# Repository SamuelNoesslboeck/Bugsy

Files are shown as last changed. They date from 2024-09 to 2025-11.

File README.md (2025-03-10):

<p align="center">
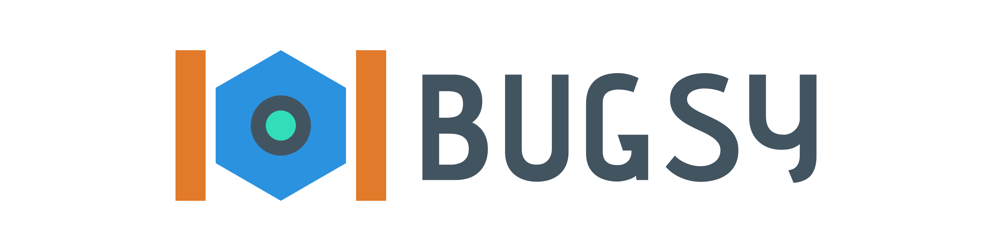
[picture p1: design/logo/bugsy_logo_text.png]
  
</p>

---

> Project creation date: 14/06/2024  

A small, robust little robot equipped with a powerful and versatile control system.

- [Code](code/README.md): Detailed description of the software with all of it's components
- [Project Log](documentation/project_log.md): A detailed project log featuring a changelog with the decisions made along the way

## Idea

Initial Design

The Bugsy is concepted as a robust little rover-like robot, that just uses two chains for movement, meaning no complex steering or other kind of movement is required.

## Control system

Basic build-up

The controls are split up into three controllers, ensuring a powerful and versatile control system, which are:
- **Core**: A *NodeMCU-32S* microcontroller, responsible for motor control and basic connections
- **Trader**: An *Arduino-Mega* microcontroller with a large set of IO-ports, responsible for peripheral devices, not required for core functionality
- **RPi**: An additional *Raspberry Pi Zero*, responsible for expensive add-ons like camera and microphone

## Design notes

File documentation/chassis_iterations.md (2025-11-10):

# Chassis iterations

The first subassembly and basis for the construction is formed by the chassis. As it defines the shape and functionality of the robot in such a fundamental way, it was remade and adjusted multiple times to best fit the needs of the construction.

### First iteration

### Second iteration - Mono-Bodies

### Third iteration - Side adjustments

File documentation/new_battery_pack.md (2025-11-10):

# New battery pack - Unlimited power

> Creation date: 03/09/2024 (yes I was that motivated on the first day)

The Bugsy uses, like most small-dimension robots, LiPo battery cells and as practical as they turn out to be, they sadly also have a lot of issues ...

## LiPo cells and their pros and cons

Probably the best thing about LiPo cells is their high energy density. That means while taking very little space they deliver decent voltage with magnificent discharge rates, even described in a special unit **C**. If a battery has 20 *C*, it can completely discharge itself from max to zero *20 times per hour*. Why such a specific unit one, including myself, might ask. However just by simply multiplying this unit with the capacity given in **Amp-Hours**, one can get the *short circuit or max output amps of this battery*. So if our battery mentioned earlier has a capacity of 1500mAh, then it can output 30000mA or 30A.

However due to the chemical reaction in such a LiPo cell it can only produce around 3.7V, meaning that it even multicell versions are drastically limited to these kind of steps:

- 1 Cell -> 3.7V
- 2 Cell -> 7.4V
- 3 Cell -> 11.1V

## Issues with these kind of voltage-steps

The problem now is that when not using special robotics motors, or when trying to get full potential out of the given electronics, these voltages are far too low compared to their possible amperage. 

Aso the gearmotors I have in use prove to be rather slow, but offer a great amount of strength even at low amperages. 

## Solution and creation of the new pack

The simple solution to this problem: Chaining multiple batteries together. Using multiple packs from the same manufacturer can increase voltages and provide a practical way to get more out of the electronics at hand.

> TODO: Insert images taken of first battery pack creation

## Upgrades and improvements to the robot through the new battery pack

The new battery pack increases the voltage of the robot up to 22.2 Volts, which also greatly increases movement speed and ease of voltage conversions.

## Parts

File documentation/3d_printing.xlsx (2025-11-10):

ID | Part Name | Version | Req. Q | Curr. Q
1 | Base plating | 0.1.0 | 2 | 1
2 | Left plating | 0.1.0 | 2 | 1
 |  |  | 1 | 1
 |  |  | 2 | 2
 |  |  | 1 | 1
Total |  |  | 8 | 6

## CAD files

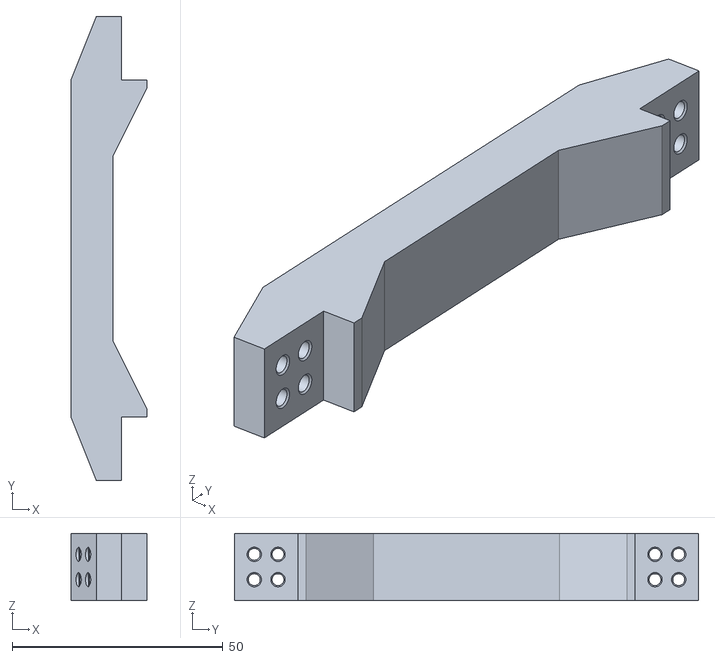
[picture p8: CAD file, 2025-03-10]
construction/a1_chassis/a1.a1_chassis_side/stl/4_side_frame.stl
18.0 x 110.0 x 16.0

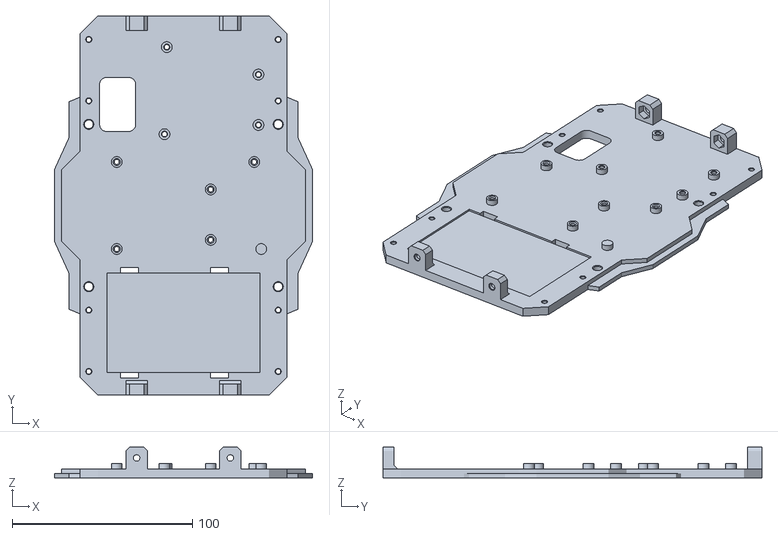
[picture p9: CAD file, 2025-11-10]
construction/a1_chassis/stl/1_2_mb_core_monobodies.stl
143.0 x 210.0 x 17.0

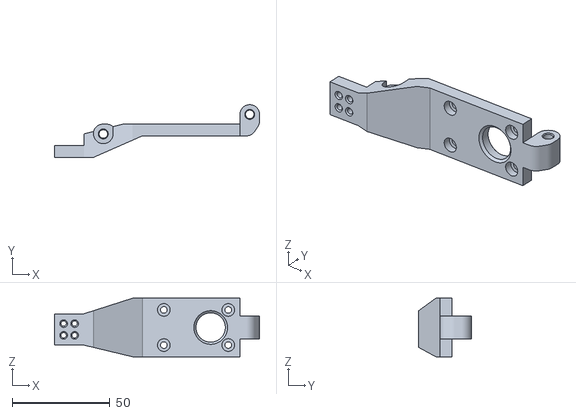
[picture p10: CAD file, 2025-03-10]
construction/a2_motor_plane/a2.a1_motor_plane_side/stl/1_frame.stl
105.0 x 27.0 x 30.0

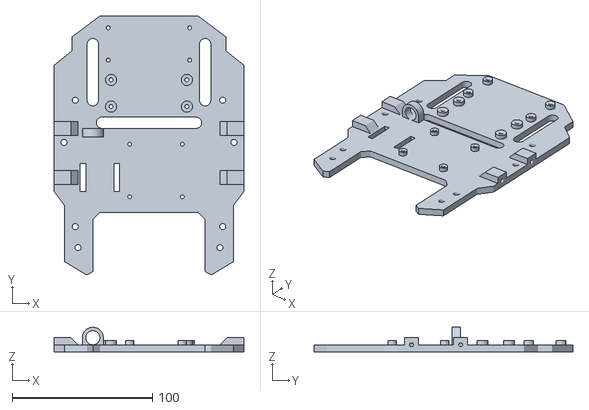
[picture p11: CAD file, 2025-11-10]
construction/a2_motor_plane/stl/1_motor_plane.stl
135.0 x 184.4 x 17.5

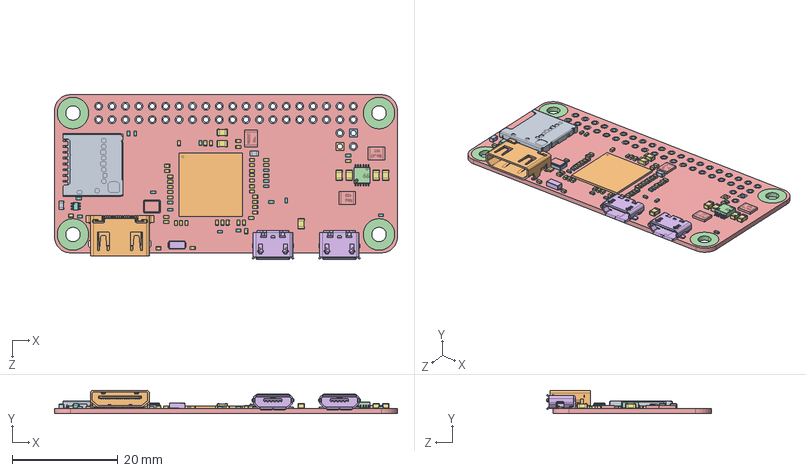
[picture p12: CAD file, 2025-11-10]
construction/electronics/e3_raspberry_pi_zero/source/raspberry_pi_zero.step
65.0 x 4.45 x 31.2 mm
Raspberry_pizero_PCB
Micro USB_input_female (short)-SMT x 2
0204 - Capacitor x 34
0204- Resistor x 17
CAP-0306 x 2
Raspberry_pizero_BCM2835 with VC4
Crystal 3.4x2.4mm
32,768 Khz Crystal
0805- Capacitor x 7
0204 - Capacitor Brown x 8
6-Pin SOT
micro sd molex
hdmi type C
Voltage Regulator 3x3mm 12-Pin
1210 inductor x 3

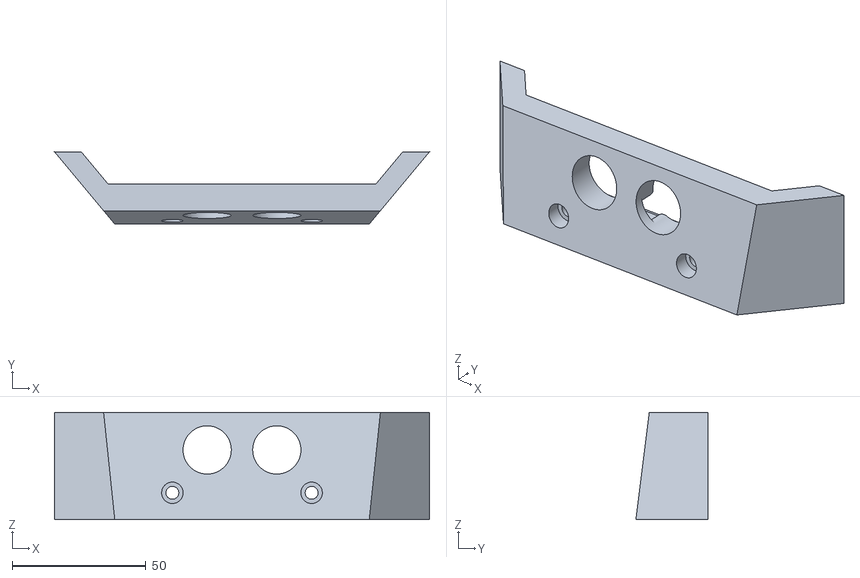
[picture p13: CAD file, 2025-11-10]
construction/stl/1_base_plating.stl
140.0 x 27.0 x 40.0

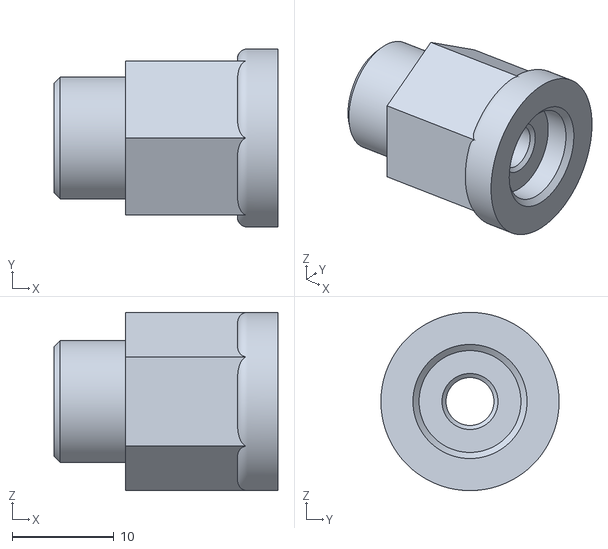
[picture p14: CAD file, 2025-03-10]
construction/a1_chassis/a1.a1_chassis_side/stl/1_wheel_connector.stl
22.0 x 17.5 x 17.5

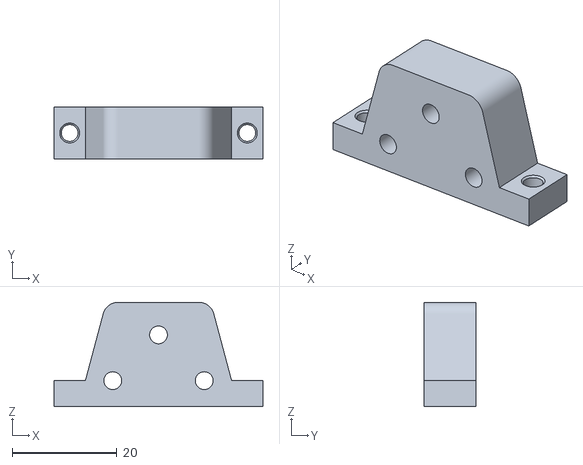
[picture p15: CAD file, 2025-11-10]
construction/a1_chassis/stl/3_wheel_connector.stl
40.0 x 10.0 x 20.0

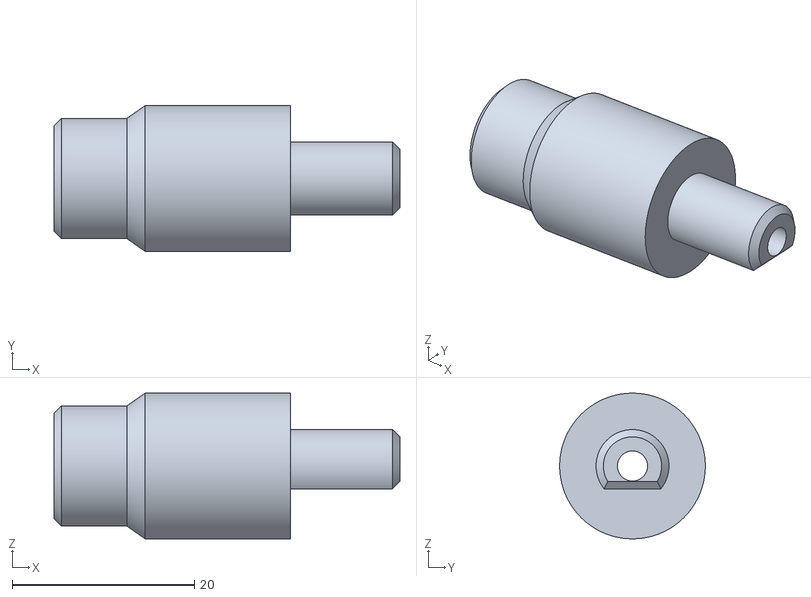
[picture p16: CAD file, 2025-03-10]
construction/a2_motor_plane/a2.a1_motor_plane_side/stl/2_gear_connector.stl
38.0 x 16.0 x 16.0

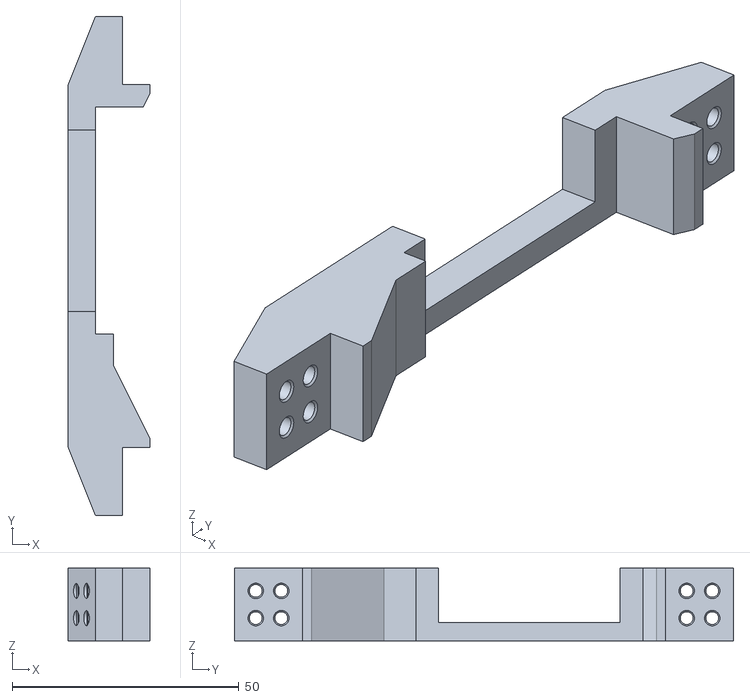
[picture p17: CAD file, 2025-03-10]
construction/a1_chassis/a1.a1_chassis_side/stl/4a_side_frame_left.stl
18.0 x 110.0 x 16.0

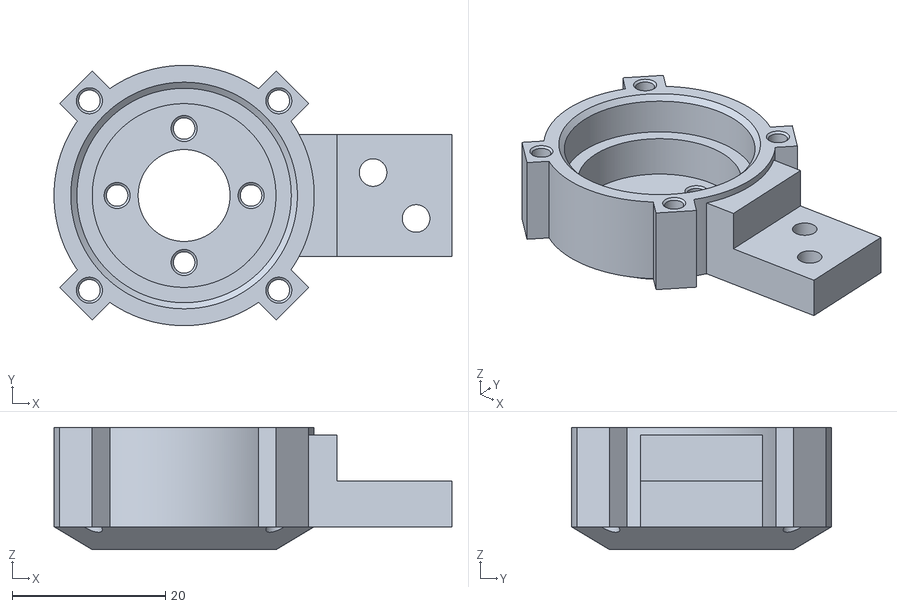
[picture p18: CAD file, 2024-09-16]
construction/a1_chassis/a1.a1_chassis_side/stl/2_bearing_case.stl
52.0 x 34.0 x 16.0

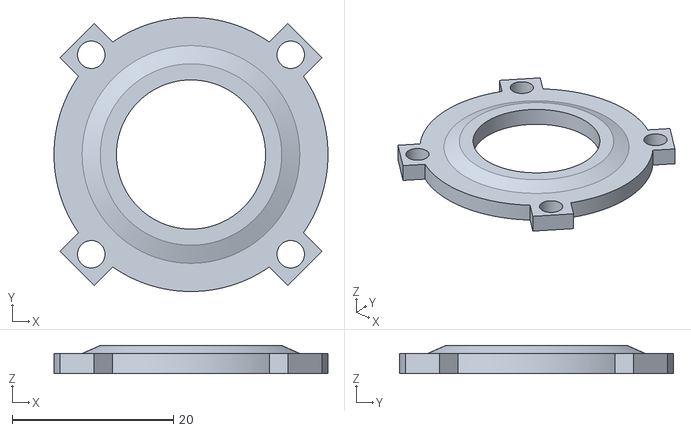
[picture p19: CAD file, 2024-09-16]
construction/a1_chassis/a1.a1_chassis_side/stl/3_bearing_cap.stl
34.0 x 34.0 x 3.50

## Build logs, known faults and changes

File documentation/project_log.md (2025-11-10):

# Project log

Here the projects creation is documented, alongside with some of the experiences I made and their impacts on the final outcome (if there is any). Some more detailed articles are listed below:

- [Design and build of new battery pack](new_battery_pack.md) (2024/09/03)
- [Chassis iterations](chasis_iterations.md) (2025/01/08)

## Design choices (2024/09/03)

The initial design intended it to look a lot more like an actually tank, but as I want it to look a little cute and the chains I bought will be rather impractical in a classical tank setup, I have chosen a newer design with a higher body and a lower back. 

Bugsy concept art

Also the addition of a logo to universally recognize the project played an important role. For more detailed info on how all these logos where created, visit the design folder of the [articles repo](https://github.com/SamuelNoesslboeck/articles).

<p align="center">
  
</p>

## Planning the components to use (2024/09/20)

Another task is to define which electrical components should be used by the Bugsy to get as much information as possible, while not spamming the network and communication methods used.

## First code (2024/10/27)

In October of 2024, I started with the first code for the microcontrollers and other hardware. Considering that I want to add a large number of remotes and internal devices like sensors and even an LCD-display, I figured that maybe the addition of another microcontroller to the Core ESP32 would be wise. 

## First build (Mk0.1.0) (2025/01/28)

Issues with the first build:

- Wheels are difficult to screw tightly to the bearings, as the driving shaft moves with the screw. 
  - Add cut-outs to the shaft to enable gripping it with tongs
- The fourth bearing is not required! Maybe install a possible mod slot?
- Install better options for cable management, currently it's rather a mess
- Print the core mono-body as one, printer size should be sufficient
- The core ESP is almost impossible to reach with a cable, make adjustments!
- More and better connectors for core parts are required

## Second iteration of first build (Mk0.1.1) (2025/02/19)

- New parts drastically improved the assembly process, however they need to be stabilized dramatically to reduce bending when tightening up the chains.
- The connector cable for the core fits through the slot, but just barely! So the next version should move the core a little bit more towards the centre
- For the larger next iteration should include a proper slot/connection for the raspberry pi
- Also, a sensor rig should be integrated, so ensure proper placement of all the sensors

## Improvements to electronics (2025/02/21)

- Adding a PCA9685 servo driver module for a better distribution of 5V power
- The module will be supplied with the voltage of the DC-DC-converter

## Second build (2025/05/03)

A few issues and notes with the second build

- For the trader MCU, the screw connector nubs broke way too easily. Either stabilize them more or be very careful in assembly
- Cable management of the lower layer is still chaos :(

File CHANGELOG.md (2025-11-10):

### 0.1.0/2024/11/28

- Introducing Changelog
- Additions to documentation, especially for code

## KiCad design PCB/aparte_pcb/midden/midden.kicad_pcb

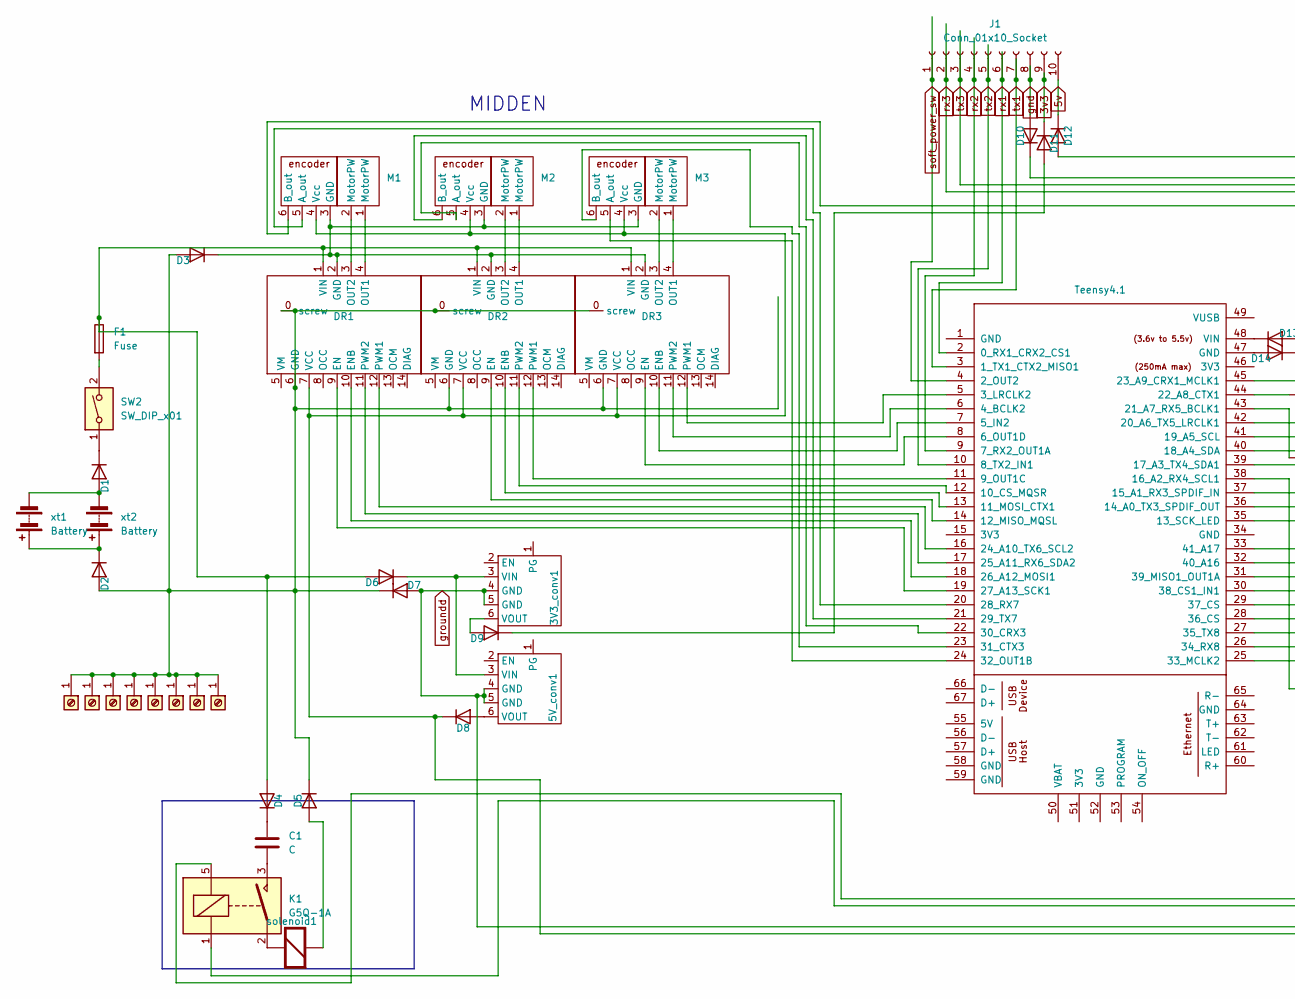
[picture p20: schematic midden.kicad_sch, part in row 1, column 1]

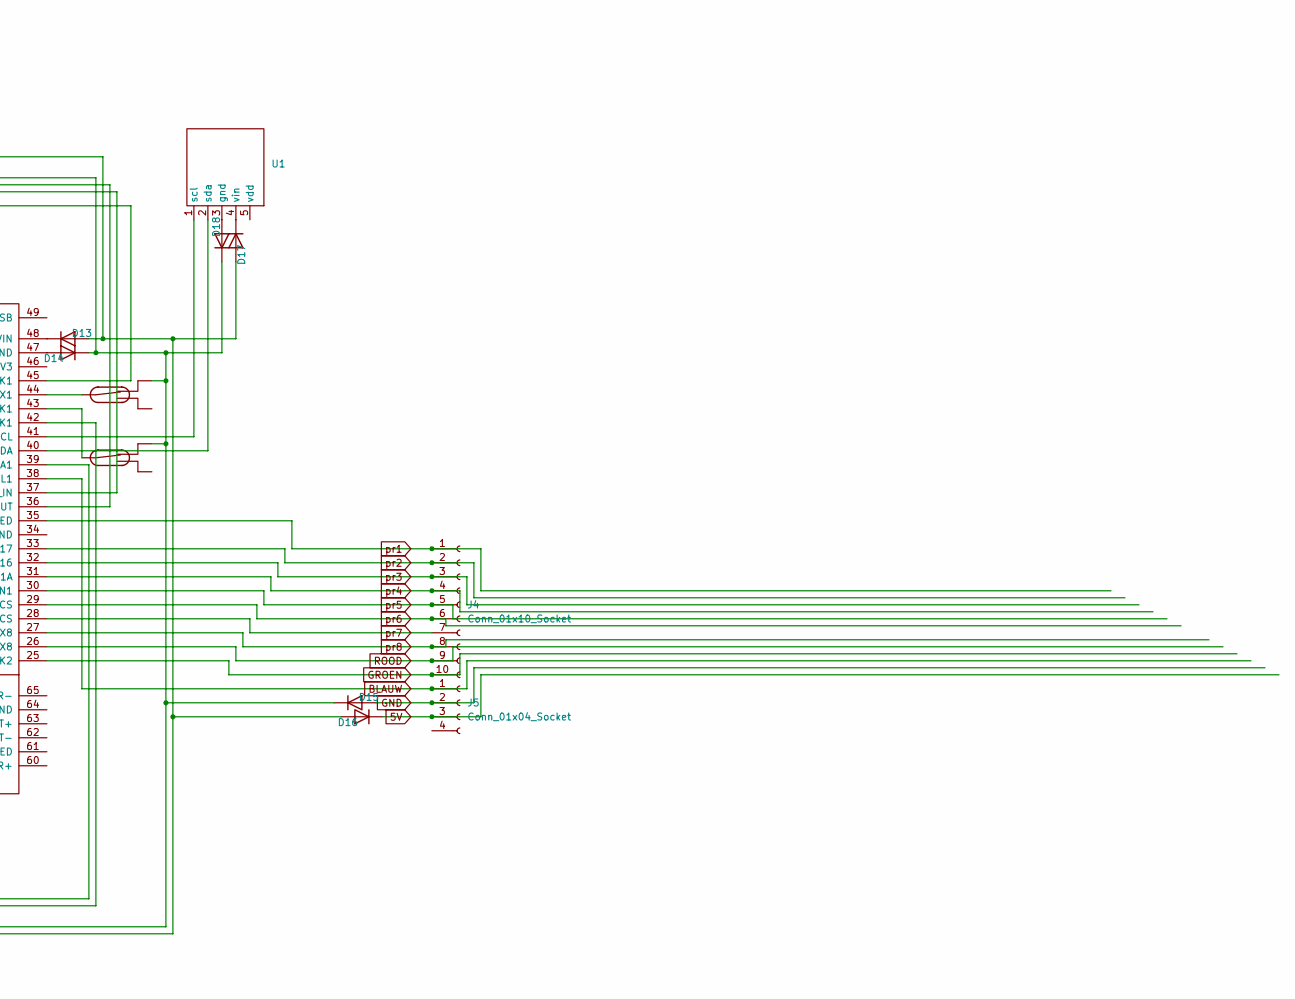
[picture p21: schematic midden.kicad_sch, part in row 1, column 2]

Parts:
3V3_conv1, 5V_conv1: pololu-d30v30fx
C1: C; CP_Radial_D8.0mm_P3.50mm
D1, D2, D3, D4, D5, D6, D7, D8, D9, D10, D11, D12, D13, D14, D15, D16, D17, D18: D; D_MELF-RM10_Universal_Handsoldering
DR1, DR2, DR3: TB9051FTG
F1: Fuse; Fuseholder_TR5_Littelfuse_No560_No460
J1, J4: Conn_01x10_Socket; JST_EH_S10B-EH_1x10_P2.50mm_Horizontal
J2, J3, J6, J7, J8, J9, J10, J11: Screw_Terminal_01x01; MountingHole_4.3mm_M4_ISO7380_Pad
J5: Conn_01x04_Socket; JST_EH_S4B-EH_1x04_P2.50mm_Horizontal
K1: G5Q-1A; Relay_SPST_Omron-G5Q-1A
M1, M2, M3: PinHeader_1x06_P1.27mm_Vertical
SW1, SW5: SW_Reed_SPDT; Mini Snap-Action Switch with 13.5mm Lever 3-Pin, SPDT, 1A
SW2: SW_DIP_x01; Rocker Switch 3-Pin, SPDT, 10A
U1: miniIMU
solenoid1: Re; Altech_AK100_1x02_P5.00mm; Rating V/Ω
teensy1: Teensy4.1; Teensy41
xt1: Battery; AMASS_XT60-F_1x02_P7.20mm_Vertical
xt2: Battery; AMASS_XT30U-M_1x02_P5.0mm_Vertical

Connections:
3v3: D11.1 (K), J1.9
5V: D16.1 (K), J5.3
5v: D12.1 (K), J1.10
BLAUW: J5.1, teensy1.38 (16_A2_RX4_SCL1)
GND: D15.2 (A), J5.2
GROEN: J4.10, teensy1.25 (33_MCLK2)
unnamed: 3V3_conv1.3 (VIN), 5V_conv1.3 (VIN), D6.1 (K)
unnamed: 3V3_conv1.6 (VOUT), D9.2 (A)
unnamed: 5V_conv1.6 (VOUT), D8.2 (A)
unnamed: C1.2, K1.3
unnamed: D1.2 (A), xt1.2 (-), xt2.2 (-)
unnamed: D1.1 (K), SW2.1
unnamed: D2.2 (A), D3.2 (A), D5.1 (K), D7.1 (K), DR1.0 (screw), DR1.6 (GND), DR2.0 (screw), DR2.6 (GND), DR3.0 (screw), DR3.6 (GND), J2.1, J3.1, J6.1, J7.1, J8.1, J9.1, J10.1, J11.1
unnamed: D2.1 (K), xt1.1 (+), xt2.1 (+)
unnamed: D3.1 (K), DR1.2 (GND), DR2.2 (GND), DR3.2 (GND), M1.3 (GND), M2.3 (GND), M3.3 (GND)
unnamed: D4.2 (A), D6.2 (A), DR1.1 (VIN), DR2.1 (VIN), DR3.1 (VIN), F1.1
unnamed: C1.1, D4.1 (K)
unnamed: D5.2 (A), solenoid1.2 (-)
unnamed: D9.1 (K), D11.2 (A)
unnamed: D8.1 (K), D12.2 (A), D13.2 (A), D16.2 (A), D17.2 (A), DR1.7 (VCC), DR2.7 (VCC), DR3.7 (VCC), M1.4 (Vcc), M2.4 (Vcc), M3.4 (Vcc)
unnamed: D13.1 (K), teensy1.48 (VIN)
unnamed: D14.2 (A), teensy1.47 (GND)
unnamed: D17.1 (K), U1.4 (vin)
unnamed: D18.2 (A), U1.3 (gnd)
unnamed: DR1.9 (EN), teensy1.19 (27_A13_SCK1)
unnamed: DR1.10 (ENB), teensy1.18 (26_A12_MOSI1)
unnamed: DR1.4 (OUT1), M1.1 (MotorPW)
unnamed: DR1.3 (OUT2), M1.2 (MotorPW)
unnamed: DR1.12 (PWM1), teensy1.16 (24_A10_TX6_SCL2)
unnamed: DR1.11 (PWM2), teensy1.17 (25_A11_RX6_SDA2)
unnamed: DR2.9 (EN), teensy1.14 (12_MISO_MQSL)
unnamed: DR2.10 (ENB), teensy1.13 (11_MOSI_CTX1)
unnamed: DR2.4 (OUT1), M2.1 (MotorPW)
unnamed: DR2.3 (OUT2), M2.2 (MotorPW)
unnamed: DR2.12 (PWM1), teensy1.11 (9_OUT1C)
unnamed: DR2.11 (PWM2), teensy1.12 (10_CS_MQSR)
unnamed: DR3.9 (EN), teensy1.8 (6_OUT1D)
unnamed: DR3.10 (ENB), teensy1.7 (5_IN2)
unnamed: DR3.4 (OUT1), M3.1 (MotorPW)
unnamed: DR3.3 (OUT2), M3.2 (MotorPW)
unnamed: DR3.12 (PWM1), teensy1.5 (3_LRCLK2)
unnamed: DR3.11 (PWM2), teensy1.6 (4_BCLK2)
unnamed: F1.2, SW2.2
unnamed: M1.5 (A_out), teensy1.20 (28_RX7)
unnamed: M1.6 (B_out), teensy1.45 (23_A9_CRX1_MCLK1)
unnamed: M2.5 (A_out), teensy1.22 (30_CRX3)
unnamed: M2.6 (B_out), teensy1.21 (29_TX7)
unnamed: M3.5 (A_out), teensy1.24 (32_OUT1B)
unnamed: M3.6 (B_out), teensy1.23 (31_CTX3)
unnamed: U1.1 (scl), teensy1.41 (19_A5_SCL)
unnamed: U1.2 (sda), teensy1.40 (18_A4_SDA)
unnamed: K1.2, solenoid1.1 (+)
unnamed: K1.5, teensy1.39 (17_A3_TX4_SDA1)
unnamed: K1.1, teensy1.42 (20_A6_TX5_LRCLK1)
unnamed: SW5.2, teensy1.43 (21_A7_RX5_BCLK1)
unnamed: SW1.2, teensy1.44 (22_A8_CTX1)
ROOD: J4.9, teensy1.26 (34_RX8)
gnd: D10.2 (A), J1.8
groundd: 3V3_conv1.4 (GND), 3V3_conv1.5 (GND), 5V_conv1.4 (GND), 5V_conv1.5 (GND), D7.2 (A), D10.1 (K), D14.1 (K), D15.1 (K), D18.1 (K), SW1.1, SW5.1
pr1: J4.1, teensy1.35 (13_SCK_LED)
pr2: J4.2, teensy1.33 (41_A17)
pr3: J4.3, teensy1.32 (40_A16)
pr4: J4.4, teensy1.31 (39_MISO1_OUT1A)
pr5: J4.5, teensy1.30 (38_CS1_IN1)
pr6: J4.6, teensy1.29 (37_CS)
pr7: J4.7, teensy1.28 (36_CS)
pr8: J4.8, teensy1.27 (35_TX8)
rx1: J1.6, teensy1.2 (0_RX1_CRX2_CS1)
rx2: J1.4, teensy1.9 (7_RX2_OUT1A)
rx3: J1.2, teensy1.37 (15_A1_RX3_SPDIF_IN)
soft_power_sw: J1.1, teensy1.4 (2_OUT2)
tx1: J1.7, teensy1.3 (1_TX1_CTX2_MISO1)
tx2: J1.5, teensy1.10 (8_TX2_IN1)
tx3: J1.3, teensy1.36 (14_A0_TX3_SPDIF_OUT)

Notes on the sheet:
MIDDEN

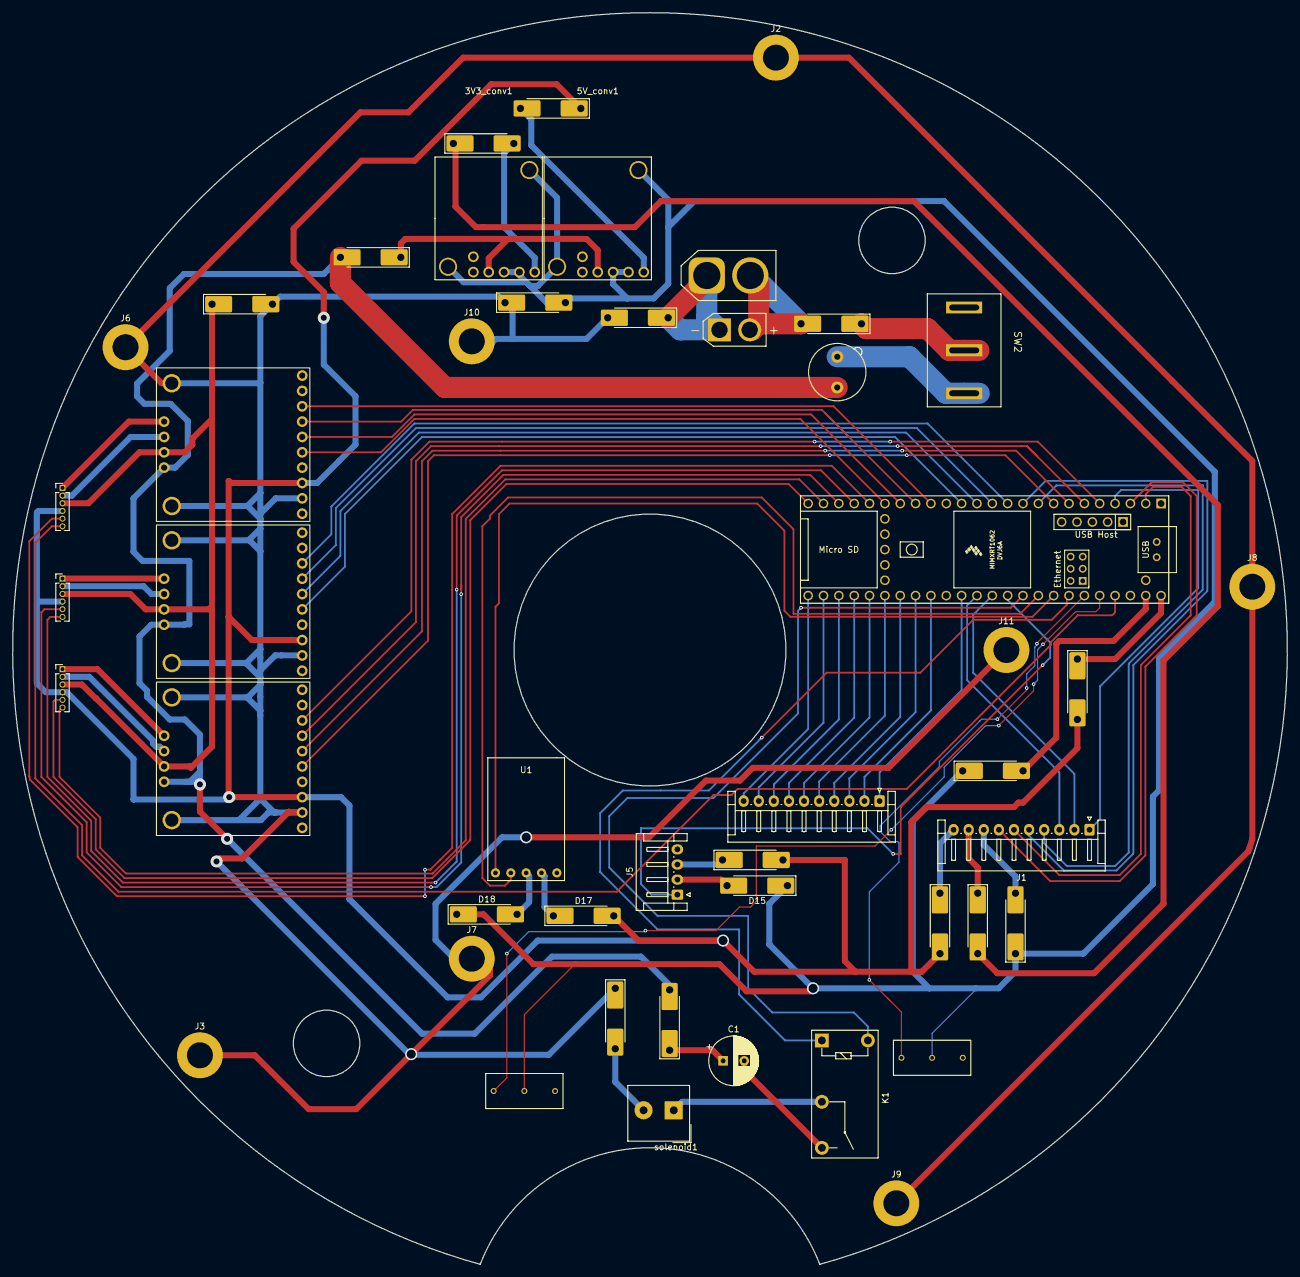
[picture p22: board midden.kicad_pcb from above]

Board: 2 copper layers, 211.0 x 207.2 mm, 48 parts (0 on the bottom side), 74 nets.

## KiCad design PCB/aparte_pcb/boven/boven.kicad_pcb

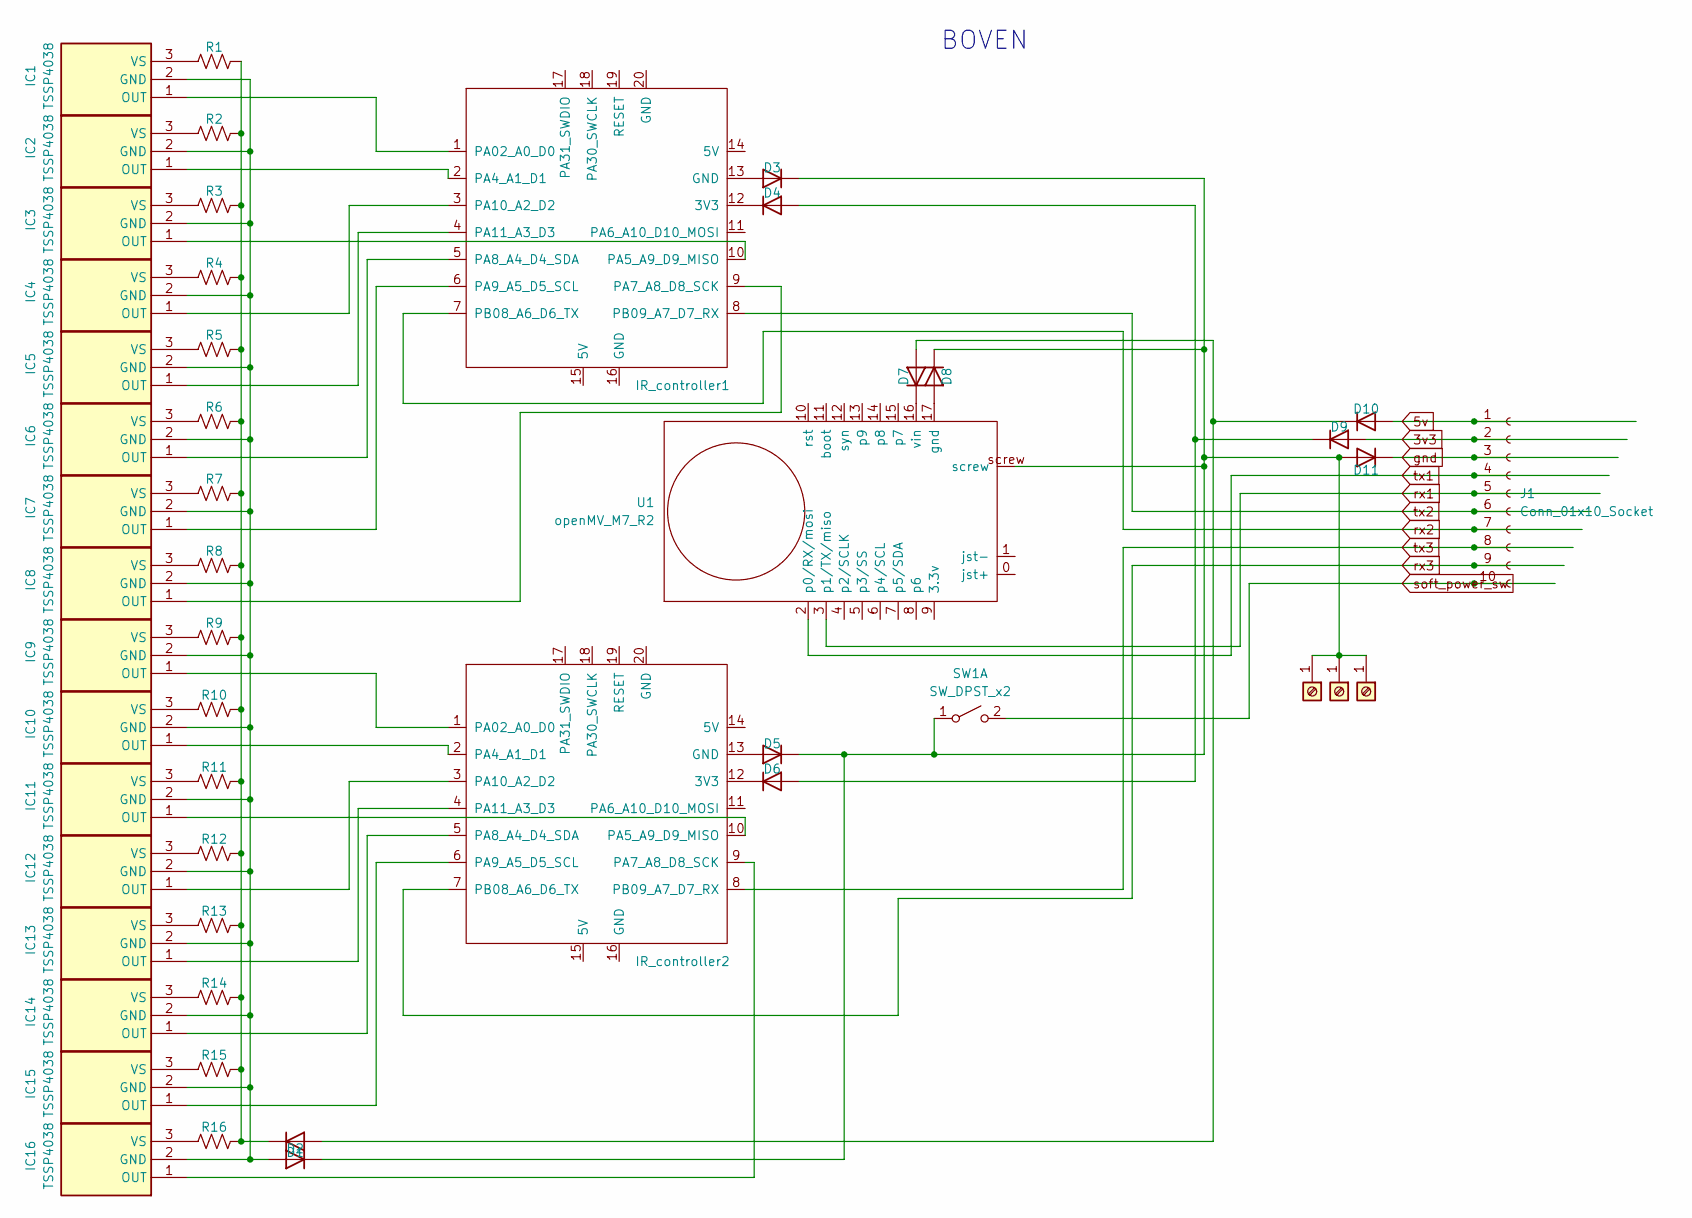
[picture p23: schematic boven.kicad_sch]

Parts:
D1, D2, D3, D4, D5, D6, D7, D8, D9, D10, D11: D; D_MELF-RM10_Universal_Handsoldering
IC1, IC2, IC3, IC4, IC5, IC6, IC7, IC8, IC9, IC10, IC11, IC12, IC13, IC14, IC15, IC16: TSSP4038; Manufacturer_Part_Number TSSP4038; Mouser Part Number 782-TSSP4038
IR_controller1, IR_controller2: Seeed Studio XIAO SAMD21; Seeduino Xiao Kicad af
J1: Conn_01x10_Socket; JST_EH_S10B-EH_1x10_P2.50mm_Horizontal
J2: Screw_Terminal_01x01; MountingHole_4.3mm_M4_DIN965_Pad
J3, J4: Screw_Terminal_01x01; MountingHole_4.3mm_M4_ISO7380_Pad
R1, R2, R3, R4, R5, R6, R7, R8, R9, R10, R11, R12, R13, R14, R15, R16: R_US; R_Axial_DIN0207_L6.3mm_D2.5mm_P10.16mm_Horizontal
SW1: SW_DPST_x2; R1966ABLKBLKEF
U1: openMV_M7_R2; openmv_m7_r2

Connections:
3v3: D9.2 (A), J1.2
5v: D10.2 (A), J1.1
unnamed: D1.2 (A), D7.2 (A), D10.1 (K)
unnamed: D1.1 (K), R1.2, R2.2, R3.2, R4.2, R5.2, R6.2, R7.2, R8.2, R9.2, R10.2, R11.2, R12.2, R13.2, R14.2, R15.2, R16.2
unnamed: D2.2 (A), IC1.2 (GND), IC2.2 (GND), IC3.2 (GND), IC4.2 (GND), IC5.2 (GND), IC6.2 (GND), IC7.2 (GND), IC8.2 (GND), IC9.2 (GND), IC10.2 (GND), IC11.2 (GND), IC12.2 (GND), IC13.2 (GND), IC14.2 (GND), IC15.2 (GND), IC16.2 (GND)
unnamed: D3.2 (A), IR_controller1.13 (GND)
unnamed: D4.2 (A), D6.2 (A), D9.1 (K)
unnamed: D4.1 (K), IR_controller1.12 (3V3)
unnamed: D5.2 (A), IR_controller2.13 (GND)
unnamed: D6.1 (K), IR_controller2.12 (3V3)
unnamed: D7.1 (K), U1.16 (vin)
unnamed: D8.2 (A), U1.17 (gnd)
unnamed: D2.1 (K), D3.1 (K), D5.1 (K), D8.1 (K), D11.2 (A), J2.1, J3.1, J4.1, SW1.1 (A), U1.screw
unnamed: IC1.1 (OUT), IR_controller1.1 (PA02_A0_D0)
unnamed: IC1.3 (VS), R1.1
unnamed: IC2.1 (OUT), IR_controller1.2 (PA4_A1_D1)
unnamed: IC2.3 (VS), R2.1
unnamed: IC3.1 (OUT), IR_controller1.10 (PA5_A9_D9_MISO)
unnamed: IC3.3 (VS), R3.1
unnamed: IC4.1 (OUT), IR_controller1.3 (PA10_A2_D2)
unnamed: IC4.3 (VS), R4.1
unnamed: IC5.1 (OUT), IR_controller1.4 (PA11_A3_D3)
unnamed: IC5.3 (VS), R5.1
unnamed: IC6.1 (OUT), IR_controller1.5 (PA8_A4_D4_SDA)
unnamed: IC6.3 (VS), R6.1
unnamed: IC7.1 (OUT), IR_controller1.6 (PA9_A5_D5_SCL)
unnamed: IC7.3 (VS), R7.1
unnamed: IC8.1 (OUT), IR_controller1.9 (PA7_A8_D8_SCK)
unnamed: IC8.3 (VS), R8.1
unnamed: IC9.1 (OUT), IR_controller2.1 (PA02_A0_D0)
unnamed: IC9.3 (VS), R9.1
unnamed: IC10.1 (OUT), IR_controller2.2 (PA4_A1_D1)
unnamed: IC10.3 (VS), R10.1
unnamed: IC11.1 (OUT), IR_controller2.10 (PA5_A9_D9_MISO)
unnamed: IC11.3 (VS), R11.1
unnamed: IC12.1 (OUT), IR_controller2.3 (PA10_A2_D2)
unnamed: IC12.3 (VS), R12.1
unnamed: IC13.1 (OUT), IR_controller2.4 (PA11_A3_D3)
unnamed: IC13.3 (VS), R13.1
unnamed: IC14.1 (OUT), IR_controller2.5 (PA8_A4_D4_SDA)
unnamed: IC14.3 (VS), R14.1
unnamed: IC15.1 (OUT), IR_controller2.6 (PA9_A5_D5_SCL)
unnamed: IC15.3 (VS), R15.1
unnamed: IC16.1 (OUT), IR_controller2.9 (PA7_A8_D8_SCK)
unnamed: IC16.3 (VS), R16.1
gnd: D11.1 (K), J1.3
rx1: J1.5, U1.3 (p1/TX/miso)
rx2: IR_controller1.7 (PB08_A6_D6_TX), J1.7
rx3: IR_controller2.7 (PB08_A6_D6_TX), J1.9
soft_power_sw: J1.10, SW1.2 (B)
tx1: J1.4, U1.2 (p0/RX/mosi)
tx2: IR_controller1.8 (PB09_A7_D7_RX), J1.6
tx3: IR_controller2.8 (PB09_A7_D7_RX), J1.8

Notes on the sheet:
BOVEN

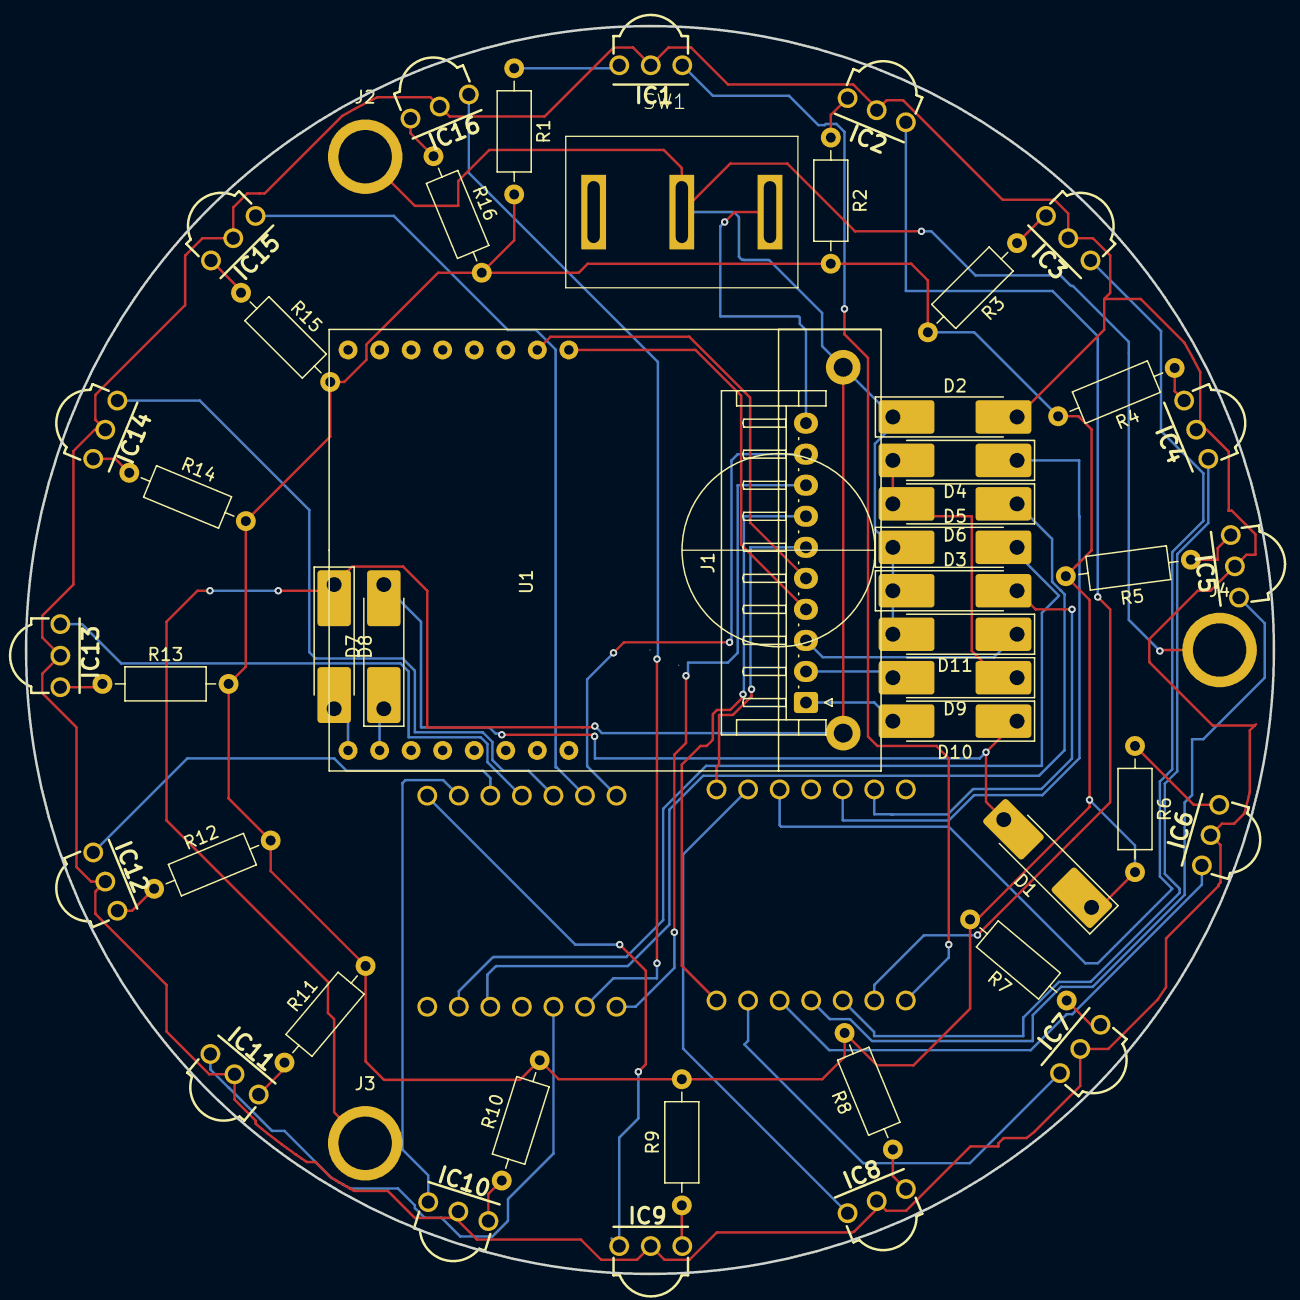
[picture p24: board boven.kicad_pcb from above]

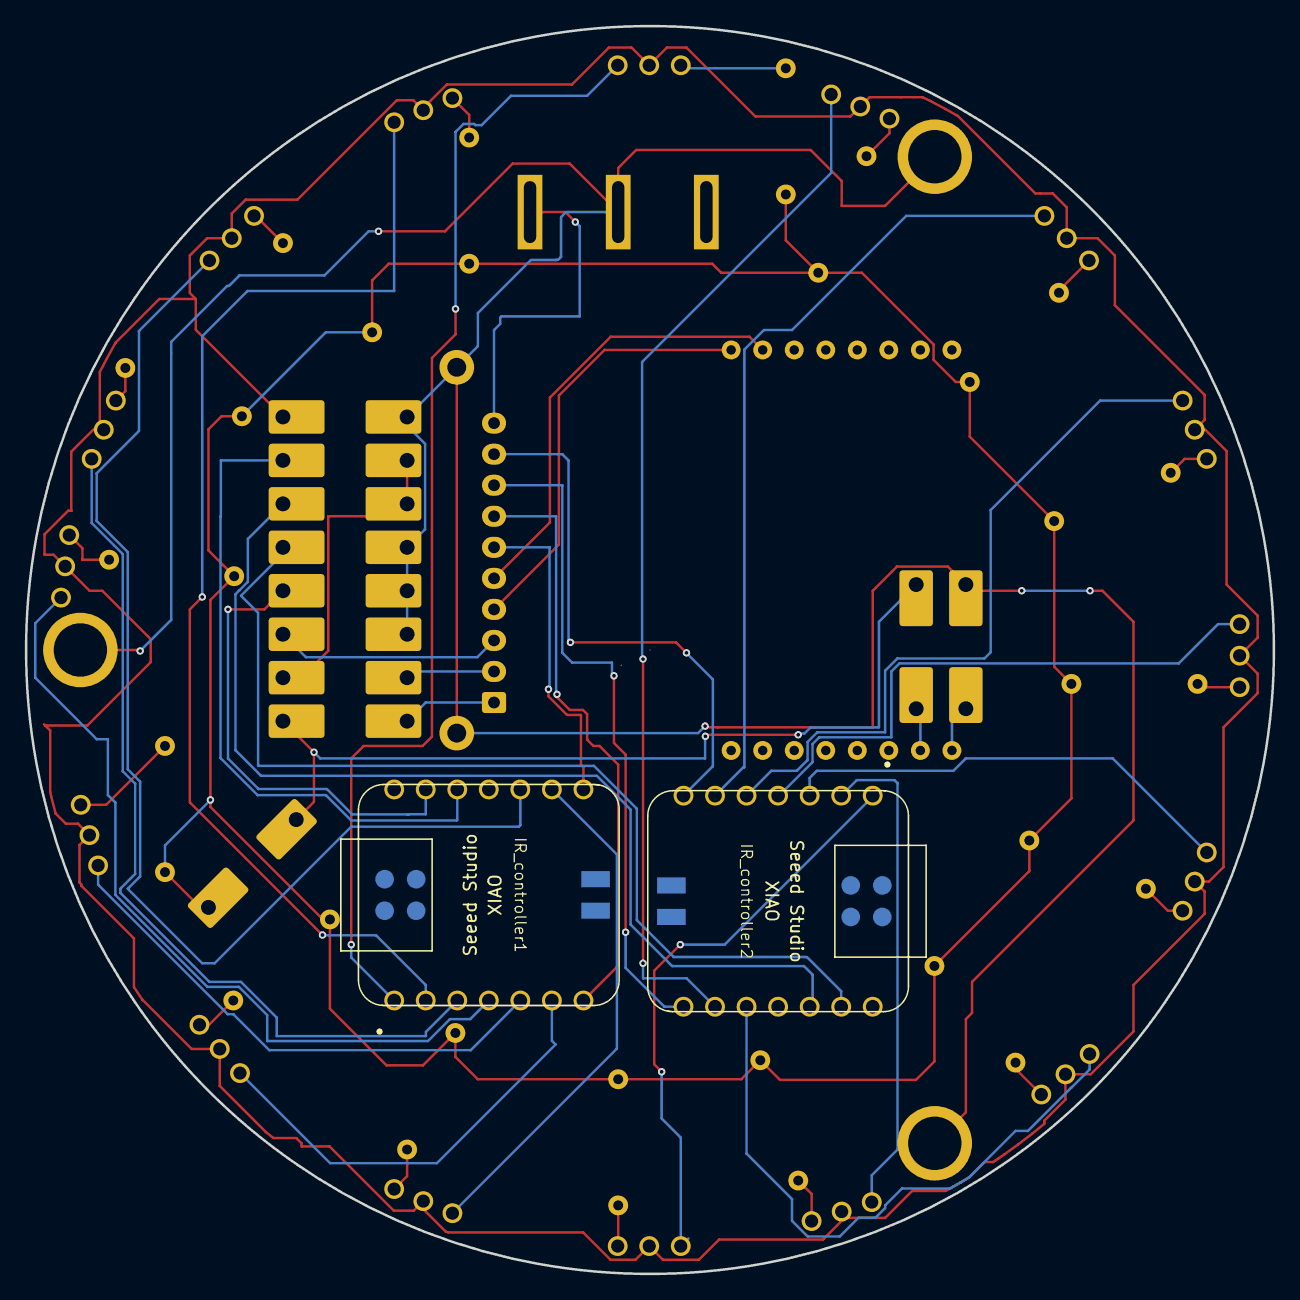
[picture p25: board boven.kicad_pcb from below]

Board: 2 copper layers, 100.5 x 100.5 mm, 51 parts (2 on the bottom side), 53 nets.

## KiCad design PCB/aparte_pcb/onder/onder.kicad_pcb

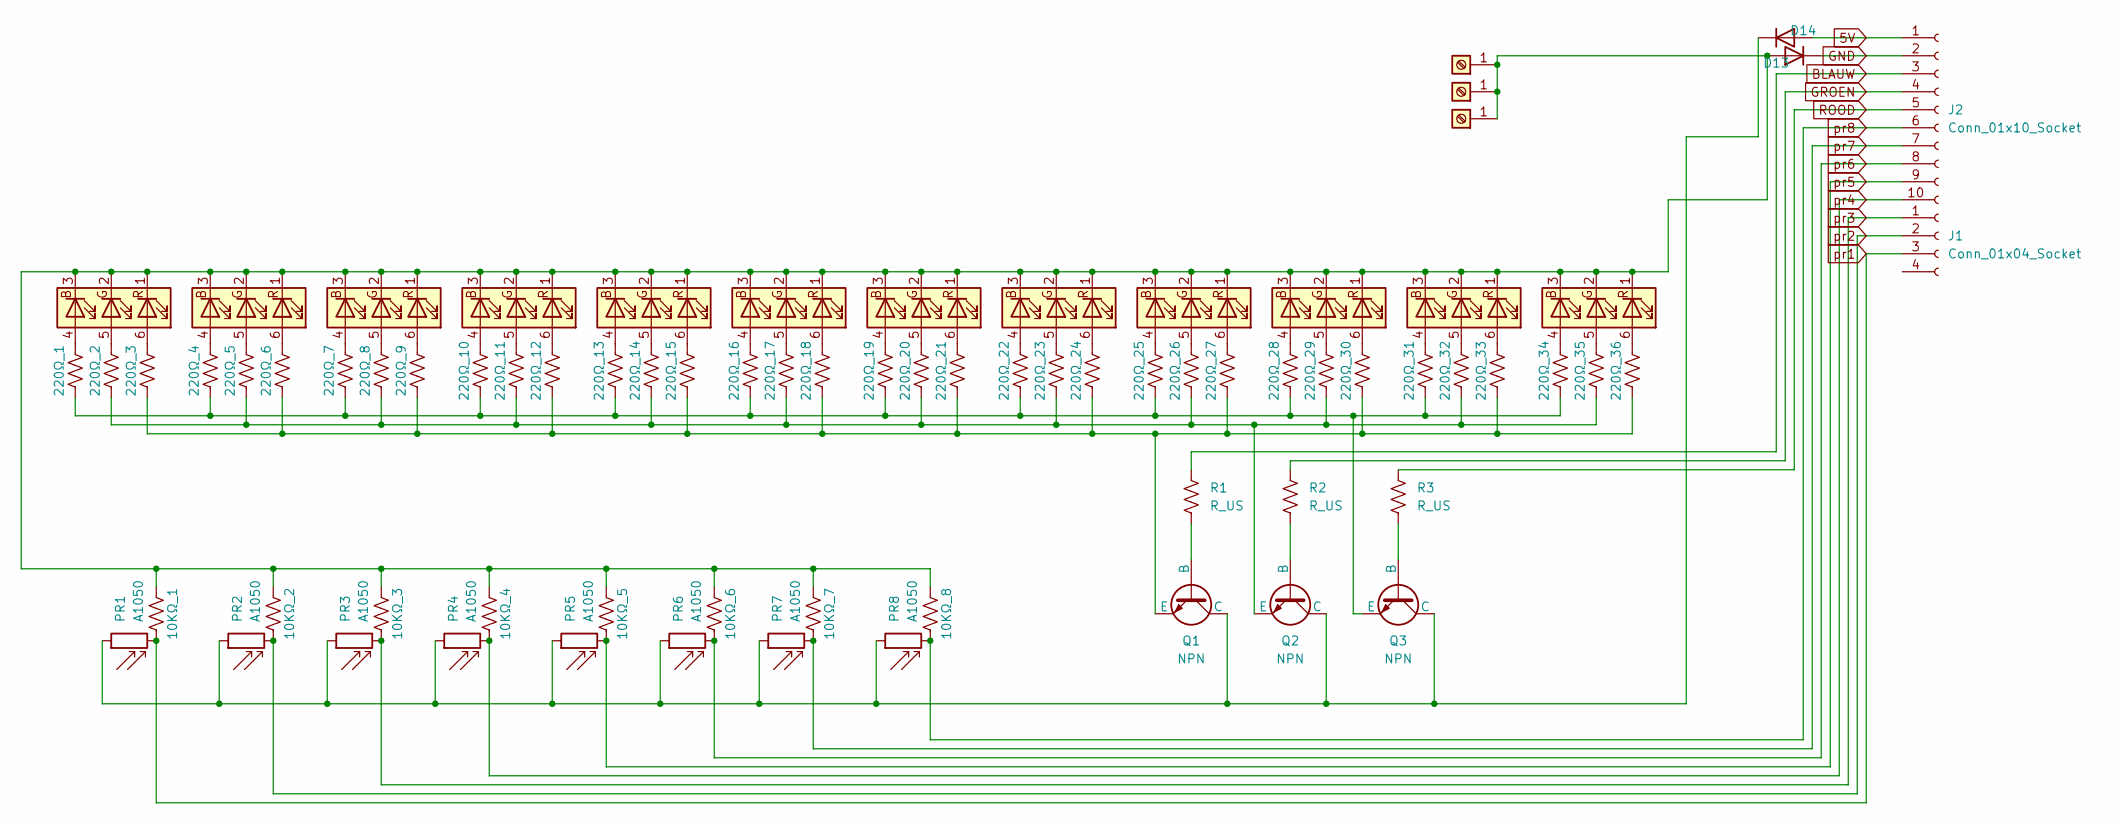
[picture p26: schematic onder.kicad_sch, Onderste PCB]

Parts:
10KΩ_1, 10KΩ_2, 10KΩ_3, 10KΩ_4, 10KΩ_5, 10KΩ_6, 10KΩ_7, 10KΩ_8, 220Ω_1, 220Ω_2, 220Ω_3, 220Ω_4, 220Ω_5, 220Ω_6, 220Ω_7, 220Ω_8, 220Ω_9, 220Ω_10, 220Ω_11, 220Ω_12, 220Ω_13, 220Ω_14, 220Ω_15, 220Ω_16, 220Ω_17, 220Ω_18, 220Ω_19, 220Ω_20, 220Ω_21, 220Ω_22, 220Ω_23, 220Ω_24, 220Ω_25, 220Ω_26, 220Ω_27, 220Ω_28, 220Ω_29, 220Ω_30, 220Ω_31, 220Ω_32, 220Ω_33, 220Ω_34, 220Ω_35, 220Ω_36: R_US; R_Axial_DIN0207_L6.3mm_D2.5mm_P10.16mm_Horizontal
D1, D2, D3, D4, D5, D6, D7, D8, D9, D10, D11, D12: LED_RGB; LED_RGB_5050-6
D13, D14: D; D_MELF-RM10_Universal_Handsoldering
J1: Conn_01x04_Socket; JST_EH_S4B-EH_1x04_P2.50mm_Horizontal
J2: Conn_01x10_Socket; JST_EH_S10B-EH_1x10_P2.50mm_Horizontal
J3, J4, J5: Screw_Terminal_01x01; MountingHole_4.3mm_M4_ISO7380_Pad
PR1, PR2, PR3, PR4, PR5, PR6, PR7, PR8: A1050; FOTORESist
Q1, Q2, Q3: NPN
R1, R2, R3: R_US; R_Axial_DIN0207_L6.3mm_D2.5mm_P10.16mm_Horizontal

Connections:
5V: D14.2 (A), J2.1
BLAUW: J2.3, R1.2
GND: D13.1 (K), J2.2
GROEN: J2.4, R2.2
unnamed: 220Ω_1.1, D1.4 (BA)
unnamed: 10KΩ_1.2, 10KΩ_2.2, 10KΩ_3.2, 10KΩ_4.2, 10KΩ_5.2, 10KΩ_6.2, 10KΩ_7.2, 10KΩ_8.2, D1.1 (RK), D1.2 (GK), D1.3 (BK), D2.1 (RK), D2.2 (GK), D2.3 (BK), D3.1 (RK), D3.2 (GK), D3.3 (BK), D4.1 (RK), D4.2 (GK), D4.3 (BK), D5.1 (RK), D5.2 (GK), D5.3 (BK), D6.1 (RK), D6.2 (GK), D6.3 (BK), D7.1 (RK), D7.2 (GK), D7.3 (BK), D8.1 (RK), D8.2 (GK), D8.3 (BK), D9.1 (RK), D9.2 (GK), D9.3 (BK), D10.1 (RK), D10.2 (GK), D10.3 (BK), D11.1 (RK), D11.2 (GK), D11.3 (BK), D12.1 (RK), D12.2 (GK), D12.3 (BK), D13.2 (A), J3.1, J4.1, J5.1
unnamed: 220Ω_2.1, D1.5 (GA)
unnamed: 220Ω_3.1, D1.6 (RA)
unnamed: 220Ω_4.1, D2.4 (BA)
unnamed: 220Ω_5.1, D2.5 (GA)
unnamed: 220Ω_6.1, D2.6 (RA)
unnamed: 220Ω_7.1, D3.4 (BA)
unnamed: 220Ω_8.1, D3.5 (GA)
unnamed: 220Ω_9.1, D3.6 (RA)
unnamed: 220Ω_10.1, D4.4 (BA)
unnamed: 220Ω_11.1, D4.5 (GA)
unnamed: 220Ω_12.1, D4.6 (RA)
unnamed: 220Ω_13.1, D5.4 (BA)
unnamed: 220Ω_14.1, D5.5 (GA)
unnamed: 220Ω_15.1, D5.6 (RA)
unnamed: 220Ω_16.1, D6.4 (BA)
unnamed: 220Ω_17.1, D6.5 (GA)
unnamed: 220Ω_18.1, D6.6 (RA)
unnamed: 220Ω_19.1, D7.4 (BA)
unnamed: 220Ω_20.1, D7.5 (GA)
unnamed: 220Ω_21.1, D7.6 (RA)
unnamed: 220Ω_22.1, D8.4 (BA)
unnamed: 220Ω_23.1, D8.5 (GA)
unnamed: 220Ω_24.1, D8.6 (RA)
unnamed: 220Ω_25.1, D9.4 (BA)
unnamed: 220Ω_26.1, D9.5 (GA)
unnamed: 220Ω_27.1, D9.6 (RA)
unnamed: 220Ω_28.1, D10.4 (BA)
unnamed: 220Ω_29.1, D10.5 (GA)
unnamed: 220Ω_30.1, D10.6 (RA)
unnamed: 220Ω_31.1, D11.4 (BA)
unnamed: 220Ω_32.1, D11.5 (GA)
unnamed: 220Ω_33.1, D11.6 (RA)
unnamed: 220Ω_34.1, D12.4 (BA)
unnamed: 220Ω_35.1, D12.5 (GA)
unnamed: 220Ω_36.1, D12.6 (RA)
unnamed: D14.1 (K), PR1.1, PR2.1, PR3.1, PR4.1, PR5.1, PR6.1, PR7.1, PR8.1, Q1.1 (C), Q2.1 (C), Q3.1 (C)
unnamed: Q1.2 (B), R1.1
unnamed: 220Ω_3.2, 220Ω_6.2, 220Ω_9.2, 220Ω_12.2, 220Ω_15.2, 220Ω_18.2, 220Ω_21.2, 220Ω_24.2, 220Ω_27.2, 220Ω_30.2, 220Ω_33.2, 220Ω_36.2, Q1.3 (E)
unnamed: Q2.2 (B), R2.1
unnamed: 220Ω_2.2, 220Ω_5.2, 220Ω_8.2, 220Ω_11.2, 220Ω_14.2, 220Ω_17.2, 220Ω_20.2, 220Ω_23.2, 220Ω_26.2, 220Ω_29.2, 220Ω_32.2, 220Ω_35.2, Q2.3 (E)
unnamed: Q3.2 (B), R3.1
unnamed: 220Ω_1.2, 220Ω_4.2, 220Ω_7.2, 220Ω_10.2, 220Ω_13.2, 220Ω_16.2, 220Ω_19.2, 220Ω_22.2, 220Ω_25.2, 220Ω_28.2, 220Ω_31.2, 220Ω_34.2, Q3.3 (E)
ROOD: J2.5, R3.2
pr1: 10KΩ_1.1, J1.3, PR1.2
pr2: 10KΩ_2.1, J1.2, PR2.2
pr3: 10KΩ_3.1, J1.1, PR3.2
pr4: 10KΩ_4.1, J2.10, PR4.2
pr5: 10KΩ_5.1, J2.9, PR5.2
pr6: 10KΩ_6.1, J2.8, PR6.2
pr7: 10KΩ_7.1, J2.7, PR7.2
pr8: 10KΩ_8.1, J2.6, PR8.2

Board: 2 copper layers, 77 parts (0 on the bottom side), 57 nets, no tracks yet.

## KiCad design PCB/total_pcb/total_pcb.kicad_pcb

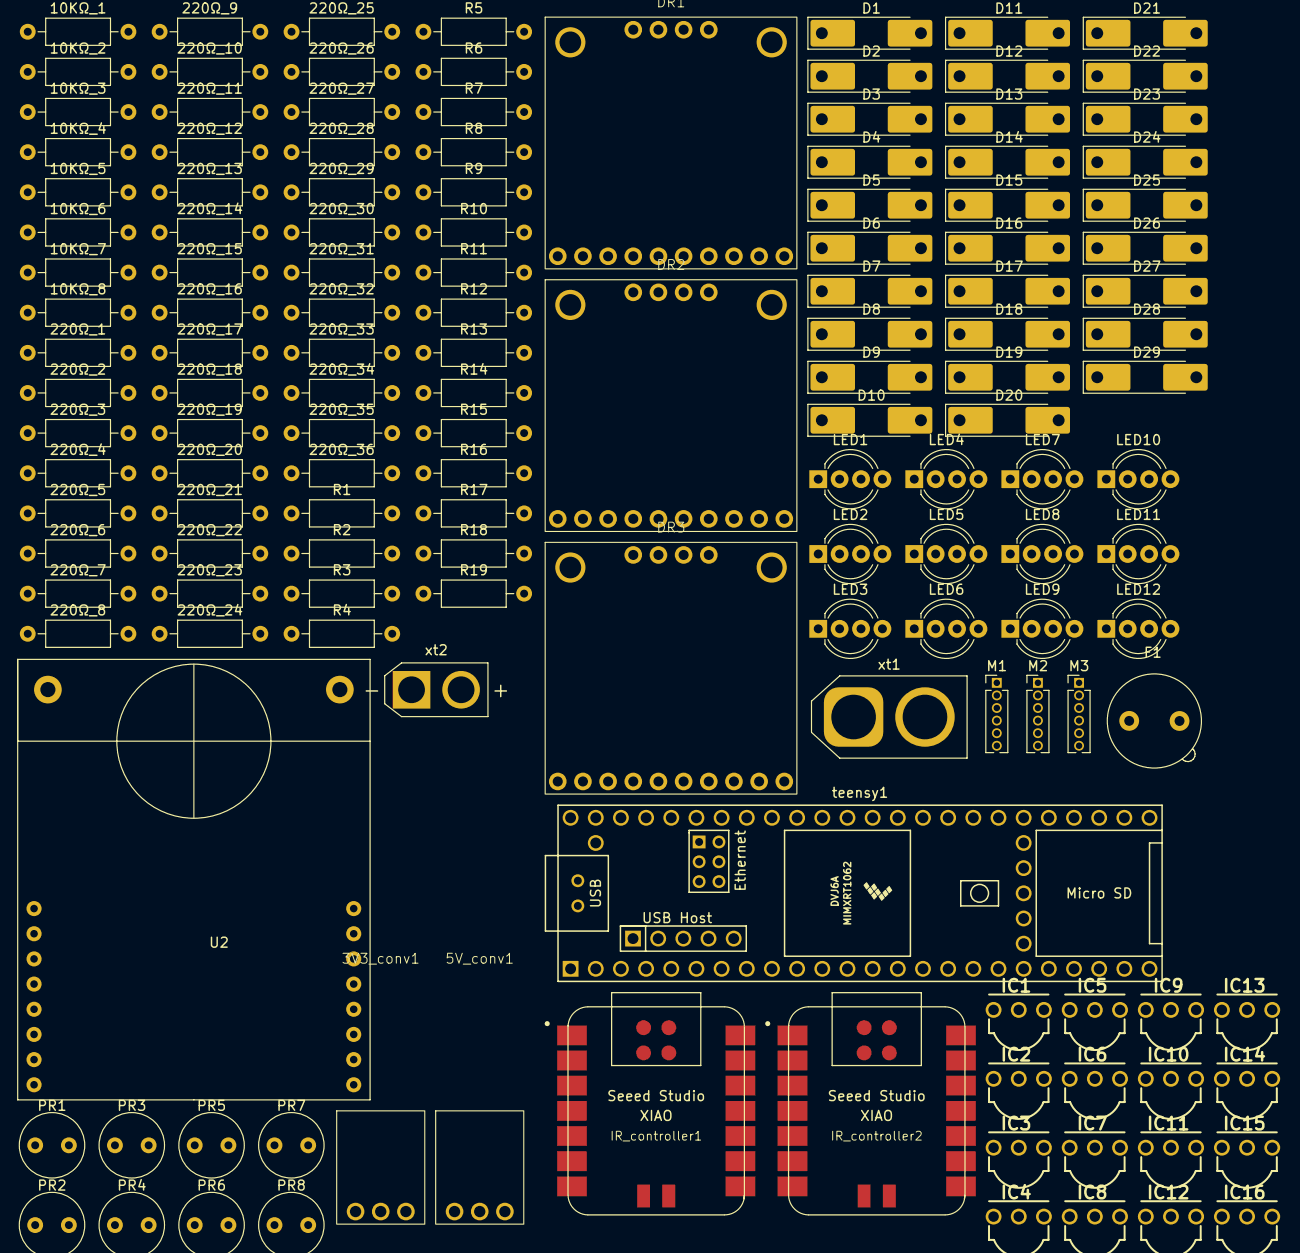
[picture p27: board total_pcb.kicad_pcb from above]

Board: 2 copper layers, 143 parts (0 on the bottom side), 140 nets, no tracks yet.

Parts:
3V3_conv1, 5V_conv1: pololu-U1V10F5
10KΩ_1, 10KΩ_2, 10KΩ_3, 10KΩ_4, 10KΩ_5, 10KΩ_6, 10KΩ_7, 10KΩ_8, 220Ω_1, 220Ω_2, 220Ω_3, 220Ω_4, 220Ω_5, 220Ω_6, 220Ω_7, 220Ω_8, 220Ω_9, 220Ω_10, 220Ω_11, 220Ω_12, 220Ω_13, 220Ω_14, 220Ω_15, 220Ω_16, 220Ω_17, 220Ω_18, 220Ω_19, 220Ω_20, 220Ω_21, 220Ω_22, 220Ω_23, 220Ω_24, 220Ω_25, 220Ω_26, 220Ω_27, 220Ω_28, 220Ω_29, 220Ω_30, 220Ω_31, 220Ω_32, 220Ω_33, 220Ω_34, 220Ω_35, 220Ω_36: R_US; R_Axial_DIN0207_L6.3mm_D2.5mm_P10.16mm_Horizontal
D1, D2, D3, D4, D5, D6, D7, D8, D9, D10, D11, D12, D13, D14, D15, D16, D17, D18, D19, D20, D21, D22, D23, D24, D25, D26, D27, D28, D29: D; D_MELF-RM10_Universal_Handsoldering
DR1, DR2, DR3: TB9051FTG
F1: Fuse; Fuseholder_TR5_Littelfuse_No560_No460
IC1, IC2, IC3, IC4, IC5, IC6, IC7, IC8, IC9, IC10, IC11, IC12, IC13, IC14, IC15, IC16: TSSP4038
IR_controller1, IR_controller2: Seeed Studio XIAO SAMD21; XIAO-SAMD21-RP2040-14P-2.54-21X17.8MM (Seeeduino XIAO)
LED1, LED2, LED3, LED4, LED5, LED6, LED7, LED8, LED9, LED10, LED11, LED12: LED_KRGB; LED_D5.0mm-4_RGB_Wide_Pins
M1, M2, M3: PinHeader_1x06_P1.27mm_Vertical
PR1, PR2, PR3, PR4, PR5, PR6, PR7, PR8: A1050; R_LDR_D6.4mm_P3.4mm_Vertical
R1, R2, R3, R4, R5, R6, R7, R8, R9, R10, R11, R12, R13, R14, R15, R16, R17, R18, R19: R_US; R_Axial_DIN0207_L6.3mm_D2.5mm_P10.16mm_Horizontal
U2: openMV_M7_R2; openmv_m7_r2
teensy1: Teensy4.1; Teensy41
xt1: Battery; AMASS_XT60-F_1x02_P7.20mm_Vertical
xt2: Battery; AMASS_XT30U-M_1x02_P5.0mm_Vertical

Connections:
3v3: D7.2 (A), D21.1 (K)
5V: D16.2 (A), D23.1 (K)
5v: D8.2 (A), D20.1 (K)
BLAUW: R17.2, teensy1.38 (16_A2_RX4_SCL1)
GND: D17.1 (K), D24.2 (A), D26.2 (A)
GROEN: R18.2, teensy1.25 (33_MCLK2)
unnamed: 3V3_conv1.3 (VIN), 5V_conv1.3 (VIN), D12.1 (K)
unnamed: D1.2 (A), D4.2 (A), D7.1 (K)
unnamed: D1.1 (K), IR_controller1.12 (3V3)
unnamed: D2.2 (A), IR_controller1.13 (GND)
unnamed: D2.1 (K), D3.1 (K), D5.1 (K), D9.2 (A), D29.1 (K), U2.screw
unnamed: D3.2 (A), IR_controller2.13 (GND)
unnamed: D4.1 (K), IR_controller2.12 (3V3)
unnamed: D5.2 (A), U2.17 (gnd)
unnamed: D6.1 (K), U2.16 (vin)
unnamed: D10.2 (A), xt1.2 (-), xt2.2 (-)
unnamed: D10.1 (K), F1.2
unnamed: D11.2 (A), D13.1 (K), D26.1 (K), D27.2 (A), DR1.0 (screw), DR1.6 (GND), DR2.0 (screw), DR2.6 (GND), DR3.0 (screw), DR3.6 (GND)
unnamed: D11.1 (K), xt1.1 (+), xt2.1 (+)
unnamed: D12.2 (A), D25.2 (A), DR1.1 (VIN), DR2.1 (VIN), DR3.1 (VIN), F1.1
unnamed: D13.2 (A), D19.1 (K), D22.1 (K), D24.1 (K)
unnamed: D14.1 (K), D18.2 (A), D20.2 (A), D23.2 (A), DR1.7 (VCC), DR2.7 (VCC), DR3.7 (VCC), M1.4 (Vcc), M2.4 (Vcc), M3.4 (Vcc)
unnamed: D15.1 (K), D21.2 (A)
unnamed: D16.1 (K), PR1.1, PR2.1, PR3.1, PR4.1, PR5.1, PR6.1, PR7.1, PR8.1
unnamed: 10KΩ_1.2, 10KΩ_2.2, 10KΩ_3.2, 10KΩ_4.2, 10KΩ_5.2, 10KΩ_6.2, 10KΩ_7.2, 10KΩ_8.2, D17.2 (A), LED1.1 (K), LED2.1 (K), LED3.1 (K), LED4.1 (K), LED5.1 (K), LED6.1 (K), LED7.1 (K), LED8.1 (K), LED9.1 (K), LED10.1 (K), LED11.1 (K), LED12.1 (K)
unnamed: D18.1 (K), teensy1.48 (VIN)
unnamed: D19.2 (A), teensy1.47 (GND)
unnamed: D27.1 (K), DR1.2 (GND), DR2.2 (GND), DR3.2 (GND), M1.3 (GND), M2.3 (GND), M3.3 (GND)
unnamed: D6.2 (A), D8.1 (K), D28.2 (A)
unnamed: D28.1 (K), R1.2, R2.2, R3.2, R4.2, R5.2, R6.2, R7.2, R8.2, R9.2, R10.2, R11.2, R12.2, R13.2, R14.2, R15.2, R16.2
unnamed: D29.2 (A), IC1.2 (GND), IC2.2 (GND), IC3.2 (GND), IC4.2 (GND), IC5.2 (GND), IC6.2 (GND), IC7.2 (GND), IC8.2 (GND), IC9.2 (GND), IC10.2 (GND), IC11.2 (GND), IC12.2 (GND), IC13.2 (GND), IC14.2 (GND), IC15.2 (GND), IC16.2 (GND)
unnamed: DR1.9 (EN), teensy1.19 (27_A13_SCK1)
unnamed: DR1.10 (ENB), teensy1.18 (26_A12_MOSI1)
unnamed: DR1.4 (OUT1), M1.1 (MotorPW)
unnamed: DR1.3 (OUT2), M1.2 (MotorPW)
unnamed: DR1.12 (PWM1), teensy1.16 (24_A10_TX6_SCL2)
unnamed: DR1.11 (PWM2), teensy1.17 (25_A11_RX6_SDA2)
unnamed: DR2.9 (EN), teensy1.14 (12_MISO_MQSL)
unnamed: DR2.10 (ENB), teensy1.13 (11_MOSI_CTX1)
unnamed: DR2.4 (OUT1), M2.1 (MotorPW)
unnamed: DR2.3 (OUT2), M2.2 (MotorPW)
unnamed: DR2.12 (PWM1), teensy1.11 (9_OUT1C)
unnamed: DR2.11 (PWM2), teensy1.12 (10_CS_MQSR)
unnamed: DR3.9 (EN), teensy1.8 (6_OUT1D)
unnamed: DR3.10 (ENB), teensy1.7 (5_IN2)
unnamed: DR3.4 (OUT1), M3.1 (MotorPW)
unnamed: DR3.3 (OUT2), M3.2 (MotorPW)
unnamed: DR3.12 (PWM1), teensy1.5 (3_LRCLK2)
unnamed: DR3.11 (PWM2), teensy1.6 (4_BCLK2)
unnamed: IC1.1 (OUT), IR_controller1.1 (PA02_A0_D0)
unnamed: IC1.3 (VS), R1.1
unnamed: IC2.1 (OUT), IR_controller1.2 (PA4_A1_D1)
unnamed: IC2.3 (VS), R2.1
unnamed: IC3.3 (VS), R3.1
unnamed: IC4.1 (OUT), IR_controller1.3 (PA10_A2_D2)
unnamed: IC4.3 (VS), R4.1
unnamed: IC5.1 (OUT), IR_controller1.4 (PA11_A3_D3)
unnamed: IC5.3 (VS), R5.1
unnamed: IC6.1 (OUT), IR_controller1.5 (PA8_A4_D4_SDA)
unnamed: IC6.3 (VS), R6.1
unnamed: IC7.1 (OUT), IR_controller1.6 (PA9_A5_D5_SCL)
unnamed: IC7.3 (VS), R7.1
unnamed: IC8.1 (OUT), IR_controller1.9 (PA7_A8_D8_SCK)
unnamed: IC8.3 (VS), R8.1
unnamed: IC9.1 (OUT), IR_controller2.1 (PA02_A0_D0)
unnamed: IC9.3 (VS), R9.1
unnamed: IC10.1 (OUT), IR_controller2.2 (PA4_A1_D1)
unnamed: IC10.3 (VS), R10.1
unnamed: IC11.3 (VS), R11.1
unnamed: IC12.1 (OUT), IR_controller2.3 (PA10_A2_D2)
unnamed: IC12.3 (VS), R12.1
unnamed: IC13.1 (OUT), IR_controller2.4 (PA11_A3_D3)
unnamed: IC13.3 (VS), R13.1
unnamed: IC14.1 (OUT), IR_controller2.5 (PA8_A4_D4_SDA)
unnamed: IC14.3 (VS), R14.1
unnamed: IC15.1 (OUT), IR_controller2.6 (PA9_A5_D5_SCL)
unnamed: IC15.3 (VS), R15.1
unnamed: IC16.1 (OUT), IR_controller2.9 (PA7_A8_D8_SCK)
unnamed: IC16.3 (VS), R16.1
unnamed: 220Ω_3.1, LED1.4 (BA)
unnamed: 220Ω_2.1, LED1.3 (GA)
unnamed: 220Ω_1.1, LED1.2 (RA)
unnamed: 220Ω_6.1, LED2.4 (BA)
unnamed: 220Ω_5.1, LED2.3 (GA)
unnamed: 220Ω_4.1, LED2.2 (RA)
unnamed: 220Ω_9.1, LED3.4 (BA)
unnamed: 220Ω_8.1, LED3.3 (GA)
unnamed: 220Ω_7.1, LED3.2 (RA)
unnamed: 220Ω_12.1, LED4.4 (BA)
unnamed: 220Ω_11.1, LED4.3 (GA)
unnamed: 220Ω_10.1, LED4.2 (RA)
unnamed: 220Ω_15.1, LED5.4 (BA)
unnamed: 220Ω_14.1, LED5.3 (GA)
unnamed: 220Ω_13.1, LED5.2 (RA)
unnamed: 220Ω_18.1, LED6.4 (BA)
unnamed: 220Ω_17.1, LED6.3 (GA)
unnamed: 220Ω_16.1, LED6.2 (RA)
unnamed: 220Ω_21.1, LED7.4 (BA)
unnamed: 220Ω_20.1, LED7.3 (GA)
unnamed: 220Ω_19.1, LED7.2 (RA)
unnamed: 220Ω_24.1, LED8.4 (BA)
unnamed: 220Ω_23.1, LED8.3 (GA)
unnamed: 220Ω_22.1, LED8.2 (RA)
unnamed: 220Ω_27.1, LED9.4 (BA)
unnamed: 220Ω_26.1, LED9.3 (GA)
unnamed: 220Ω_25.1, LED9.2 (RA)
unnamed: 220Ω_30.1, LED10.4 (BA)
unnamed: 220Ω_29.1, LED10.3 (GA)
unnamed: 220Ω_28.1, LED10.2 (RA)
unnamed: 220Ω_33.1, LED11.4 (BA)
unnamed: 220Ω_32.1, LED11.3 (GA)
unnamed: 220Ω_31.1, LED11.2 (RA)
unnamed: 220Ω_36.1, LED12.4 (BA)
unnamed: 220Ω_35.1, LED12.3 (GA)
unnamed: 220Ω_34.1, LED12.2 (RA)
unnamed: M1.5 (A_out), teensy1.20 (28_RX7)
unnamed: M1.6 (B_out), teensy1.45 (23_A9_CRX1_MCLK1)
unnamed: M2.5 (A_out), teensy1.22 (30_CRX3)
unnamed: M2.6 (B_out), teensy1.21 (29_TX7)
unnamed: M3.5 (A_out), teensy1.24 (32_OUT1B)
unnamed: M3.6 (B_out), teensy1.23 (31_CTX3)
unnamed: 220Ω_3.2, 220Ω_6.2, 220Ω_9.2, 220Ω_12.2, 220Ω_15.2, 220Ω_18.2, 220Ω_21.2, 220Ω_24.2, 220Ω_27.2, 220Ω_30.2, 220Ω_33.2, 220Ω_36.2
unnamed: 220Ω_2.2, 220Ω_5.2, 220Ω_8.2, 220Ω_11.2, 220Ω_14.2, 220Ω_17.2, 220Ω_20.2, 220Ω_23.2, 220Ω_26.2, 220Ω_29.2, 220Ω_32.2, 220Ω_35.2
unnamed: 220Ω_1.2, 220Ω_4.2, 220Ω_7.2, 220Ω_10.2, 220Ω_13.2, 220Ω_16.2, 220Ω_19.2, 220Ω_22.2, 220Ω_25.2, 220Ω_28.2, 220Ω_31.2, 220Ω_34.2
ROOD: R19.2, teensy1.26 (34_RX8)
gnd: D9.1 (K), D22.2 (A)
pr1: 10KΩ_1.1, PR1.2, teensy1.35 (13_SCK_LED)
pr2: 10KΩ_2.1, PR2.2, teensy1.33 (41_A17)
pr3: 10KΩ_3.1, PR3.2, teensy1.32 (40_A16)
pr4: 10KΩ_4.1, PR4.2, teensy1.31 (39_MISO1_OUT1A)
pr5: 10KΩ_5.1, PR5.2, teensy1.30 (38_CS1_IN1)
pr6: 10KΩ_6.1, PR6.2, teensy1.29 (37_CS)
pr7: 10KΩ_7.1, PR7.2, teensy1.28 (36_CS)
pr8: 10KΩ_8.1, PR8.2, teensy1.27 (35_TX8)
rx1: U2.3 (p1/TX/miso), teensy1.2 (0_RX1_CRX2_CS1)
rx2: IR_controller1.7 (PB08_A6_D6_TX), teensy1.9 (7_RX2_OUT1A)
rx3: IR_controller2.7 (PB08_A6_D6_TX), teensy1.37 (15_A1_RX3_SPDIF_IN)
tx1: U2.2 (p0/RX/mosi), teensy1.3 (1_TX1_CTX2_MISO1)
tx2: IR_controller1.8 (PB09_A7_D7_RX), teensy1.10 (8_TX2_IN1)
tx3: IR_controller2.8 (PB09_A7_D7_RX), teensy1.36 (14_A0_TX3_SPDIF_OUT)

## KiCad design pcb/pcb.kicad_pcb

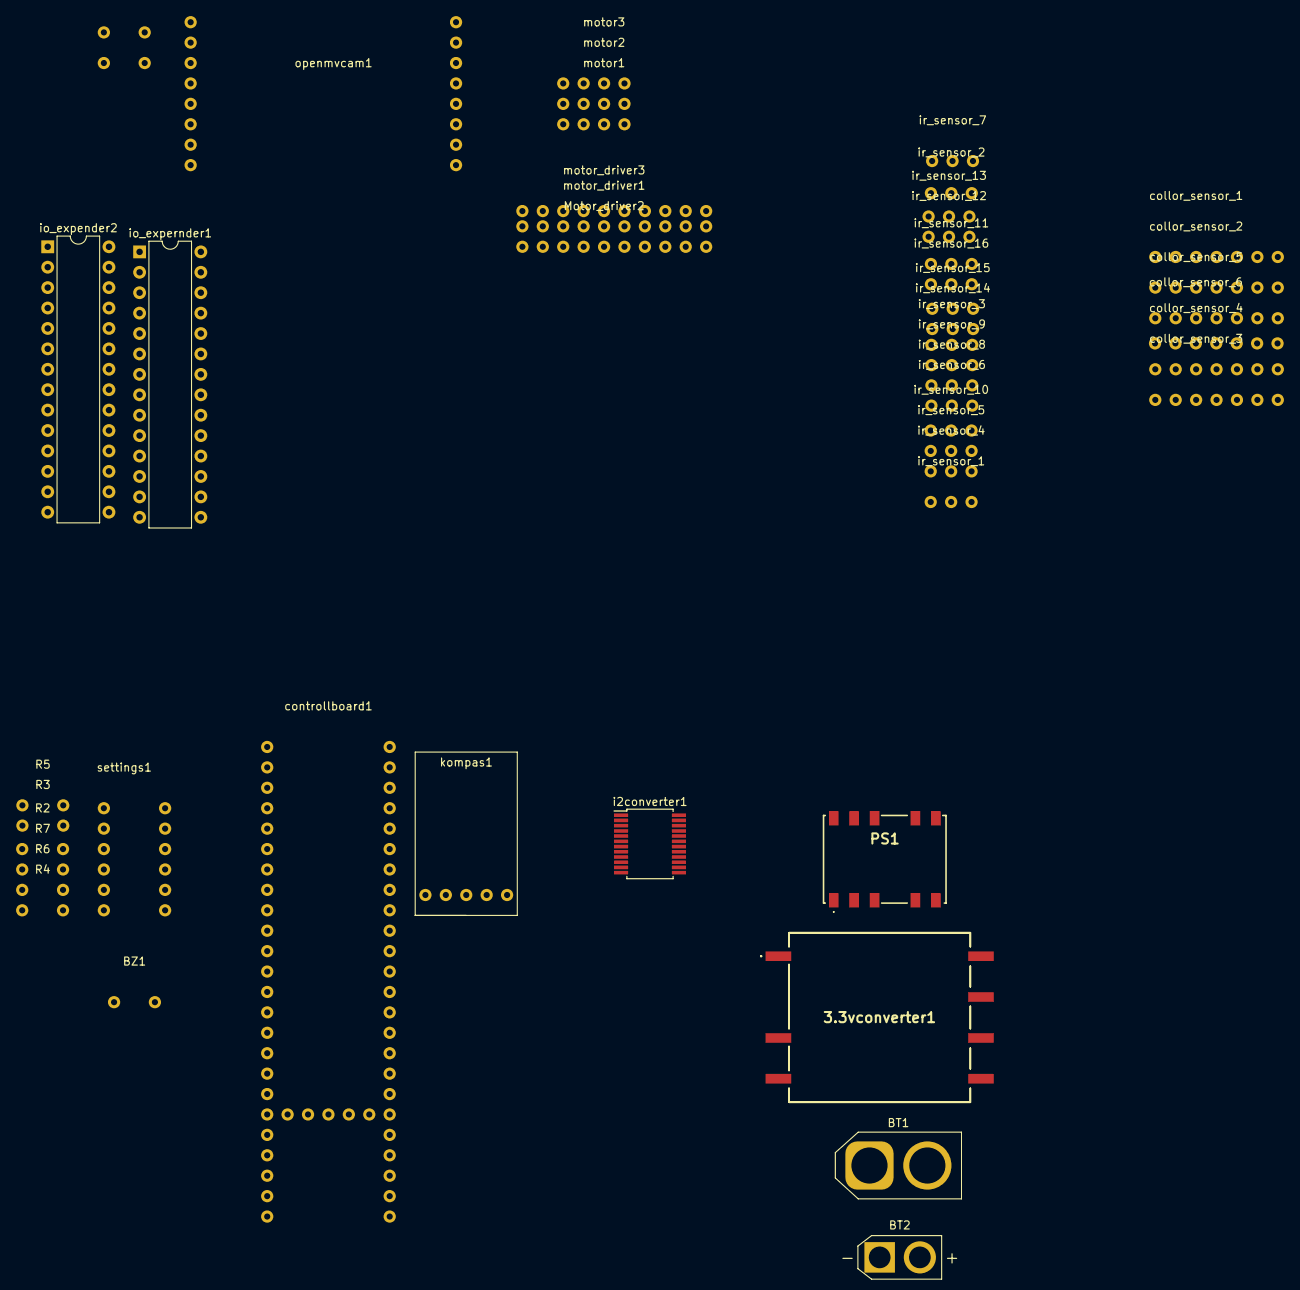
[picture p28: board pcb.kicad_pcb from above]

Board: 2 copper layers, 48 parts (0 on the bottom side), 67 nets, no tracks yet.

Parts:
3.3vconverter1: CC6-1203SR-E; CC60512SRE
BT1: Battery; AMASS_XT60-F_1x02_P7.20mm_Vertical
BT2: Battery; AMASS_XT30U-F_1x02_P5.0mm_Vertical
BZ1: Buzzer; buzer
Motor_driver2: TB9051FTG
PS1: SFTN01M-05N; SFTN01M05N
R1, R2, R3, R4, R5, R6, R7: R; resistor
collor_sensor_1, collor_sensor_2, collor_sensor_3, collor_sensor_4, collor_sensor_5, collor_sensor_6: tcs3472_color_sensor; tcs3472
controllboard1: Teensy4.1; teensy4.1
i2converter1: PCA9548ADB; SSOP-24_5.3x8.2mm_P0.65mm
io_expender2: MCP23017_SP; DIP-28_W7.62mm
io_expernder1: MCP23017_SP; DIP-28_W7.62mm
ir_sensor_1, ir_sensor_2, ir_sensor_3, ir_sensor_4, ir_sensor_5, ir_sensor_6, ir_sensor_7, ir_sensor_8, ir_sensor_9, ir_sensor_10, ir_sensor_11, ir_sensor_12, ir_sensor_13, ir_sensor_14, ir_sensor_15, ir_sensor_16: tssp4038
kompas1: miniIMU-9_v6
motor1, motor2, motor3: pololu_motor
motor_driver1, motor_driver3: TB9051FTG
openmvcam1: openMV_M7_R2; openmv_m7_r2
set_goal_color1: SW_DIP_x01; dipswitch1
settings1: SW_DIP_x06; dipswitch6

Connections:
12v: 3.3vconverter1.1, BT1.2, BT2.2, PS1.2
unnamed: 3.3vconverter1.5, R1.2, collor_sensor_1.3, collor_sensor_2.3, collor_sensor_3.3, collor_sensor_4.3, collor_sensor_5.3, collor_sensor_6.3, i2converter1.12, io_expender2.10, io_expernder1.10, ir_sensor_1.2, ir_sensor_2.2, ir_sensor_3.2, ir_sensor_4.2, ir_sensor_5.2, ir_sensor_6.2, ir_sensor_7.2, ir_sensor_8.2, ir_sensor_9.2, ir_sensor_10.2, ir_sensor_11.2, ir_sensor_12.2, ir_sensor_13.2, ir_sensor_14.2, ir_sensor_15.2, ir_sensor_16.2
unnamed: 3.3vconverter1.7, collor_sensor_1.2, collor_sensor_2.2, collor_sensor_3.2, collor_sensor_4.2, collor_sensor_5.2, collor_sensor_6.2, i2converter1.24, io_expender2.9, io_expernder1.9, ir_sensor_1.1, ir_sensor_2.1, ir_sensor_3.1, ir_sensor_4.1, ir_sensor_5.1, ir_sensor_6.1, ir_sensor_7.1, ir_sensor_8.1, ir_sensor_9.1, ir_sensor_10.1, ir_sensor_11.1, ir_sensor_12.1, ir_sensor_13.1, ir_sensor_14.1, ir_sensor_15.1, ir_sensor_16.1, set_goal_color1.1
unnamed: BZ1.1, controllboard1.10
unnamed: BZ1.2, Motor_driver2.6, PS1.5, R2.2, R3.2, R4.2, R5.2, R6.2, R7.2, controllboard1.47, kompas1.2, motor1.4, motor2.4, motor3.4, motor_driver1.6, motor_driver3.6
unnamed: Motor_driver2.7, PS1.8, controllboard1.48, kompas1.3, motor1.1, motor2.1, motor3.1, motor_driver1.7, motor_driver3.7
unnamed: Motor_driver2.9, io_expender2.5
unnamed: Motor_driver2.10, io_expender2.4
unnamed: Motor_driver2.11, io_expender2.3
unnamed: Motor_driver2.12, io_expender2.2
unnamed: R1.1, set_goal_color1.2
unnamed: R2.1, controllboard1.4, settings1.7
unnamed: R3.1, controllboard1.5, settings1.8
unnamed: R4.1, controllboard1.6, settings1.9
unnamed: R5.1, controllboard1.7, settings1.10
unnamed: R6.1, controllboard1.8, settings1.11
unnamed: R7.1, controllboard1.9, settings1.12
unnamed: collor_sensor_1.0, i2converter1.15
unnamed: collor_sensor_1.1, i2converter1.16
unnamed: collor_sensor_2.0, i2converter1.13
unnamed: collor_sensor_2.1, i2converter1.14
unnamed: collor_sensor_3.0, i2converter1.10
unnamed: collor_sensor_3.1, i2converter1.11
unnamed: collor_sensor_4.0, i2converter1.9
unnamed: collor_sensor_4.1, i2converter1.8
unnamed: collor_sensor_5.0, i2converter1.6
unnamed: collor_sensor_5.1, i2converter1.7
unnamed: collor_sensor_6.0, i2converter1.4
unnamed: collor_sensor_6.1, i2converter1.5
unnamed: controllboard1.40, i2converter1.23, kompas1.1
unnamed: controllboard1.41, i2converter1.22, kompas1.0
unnamed: controllboard1.44, motor_driver3.11
unnamed: controllboard1.45, motor_driver3.12
unnamed: controllboard1.46, settings1.1, settings1.2, settings1.3, settings1.4, settings1.5, settings1.6
unnamed: i2converter1.17, io_expernder1.13
unnamed: i2converter1.18, io_expernder1.12
unnamed: i2converter1.19, io_expender2.13
unnamed: i2converter1.20, io_expender2.12
unnamed: io_expender2.1, motor_driver3.9
unnamed: io_expender2.6, motor_driver1.12
unnamed: io_expender2.7, motor_driver1.11
unnamed: io_expender2.8, motor_driver1.10
unnamed: io_expender2.21, motor_driver1.9
unnamed: io_expender2.22, ir_sensor_15.3
unnamed: io_expender2.23, ir_sensor_14.3
unnamed: io_expender2.24, motor_driver3.10
unnamed: io_expender2.25, motor2.2
unnamed: io_expender2.26, motor2.3
unnamed: io_expender2.27, motor3.2
unnamed: io_expender2.28, motor3.3
unnamed: io_expernder1.1, ir_sensor_1.3
unnamed: io_expernder1.2, ir_sensor_2.3
unnamed: io_expernder1.3, ir_sensor_4.3
unnamed: io_expernder1.4, ir_sensor_5.3
unnamed: io_expernder1.5, ir_sensor_6.3
unnamed: io_expernder1.6, ir_sensor_7.3
unnamed: io_expernder1.7, ir_sensor_8.3
unnamed: io_expernder1.8, ir_sensor_9.3
unnamed: io_expernder1.21, ir_sensor_10.3
unnamed: io_expernder1.22, ir_sensor_11.3
unnamed: io_expernder1.23, ir_sensor_12.3
unnamed: io_expernder1.24, ir_sensor_13.3
unnamed: io_expernder1.25, ir_sensor_16.3
unnamed: io_expernder1.26, ir_sensor_3.3
unnamed: io_expernder1.27, motor1.2
unnamed: io_expernder1.28, motor1.3
gnd: 3.3vconverter1.3, BT1.1, BT2.1, PS1.1

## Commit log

2024-09-16 advancing cad
    [1_wheel_connector.stl, 1_wheel_connector_x4.3mf, 2_3_bearing_mount.3mf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]
2024-09-17 further planning on chasis
    [a1.1_chasis_side.cfg, a1_chasis.cfg, a_bugsy.cfg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]
2024-09-24 new parts
    [a1.1_chasis_side.cfg, a1_chasis.cfg, a2_body.cfg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]
2024-10-28 first version of bugsy code
    [a1_chasis.cfg]
2024-10-30 starting full ble switch
2024-11-08 removing arduino.json files
2024-11-11 adding electronics and further progress on moonbug
    [Bugsy.kicad_pcb, Bugsy.kicad_sch]
2024-11-12 new code and schematics
    [Bugsy.kicad_sch]
2024-11-13 adding small cad changes
    [a1_chasis.cfg, a_bugsy.cfg]
2024-11-28 adding new code schematics
2025-01-04 first changes for new construction
    [a1_chasis.cfg]
2025-01-04 further additions to core monobodies
    [1_rear_monobody.3mf, a1_chasis.cfg]
2025-01-06 finishing core monobody
    [2_front_monobody.3mf, 5_side_frame.3mf, 5_side_frame.stl]
2025-01-07 removing old body parts
    [a2_body.cfg]
2025-01-08 included asymetrical side shape for connectors
    [5a_side_frame_left.cfg, a1.1a_chasis_side_left.cfg, a1_chasis.cfg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]
2025-01-09 cad changes
    [5_side_frame_x2.3mf, 5a_side_frame_left.3mf, 5a_side_frame_left.stl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]
2025-01-12 start of motor plane frame parts
    [a2.1_motor_plane_side.cfg, n1_jgy-370.cfg]
2025-01-12 small progress on side frame parts
    [a2.1_motor_plane_side.cfg]
2025-01-16 improving frame
    [a_bugsy.cfg]
2025-01-17 improving motor side
    [a2.1_motor_plane_side.cfg, n2_[6001].cfg]
2025-01-19 new motor layer
    [a2.1_motor_plane_side.cfg, a2_motor_plane.cfg, a_bugsy.cfg]
2025-01-22 adding motor plane to main assembly
    [1_wheel_connector.stl, 1_wheel_connector_x2.3mf, 2_3_bearing_mount.3mf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]
2025-01-23 adding chains and gears
    [a2.1_motor_plane_side.cfg, a2_motor_plane.cfg, a_bugsy.cfg]
2025-01-23 first core build
    [1_motor_plane.3mf, 1_motor_plane.stl, 5_gear_connector.3mf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]
2025-01-28 massive code and construction improvements
    [1_2_mb_core_monobodies.3mf, 1_motor_plane.stl, 3_wheel_connector.stl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]
2025-01-31 updated construction to new connector
    [a2_motor_plane.cfg, a_bugsy.cfg]
2025-02-02 new wheel and side conenctor
    [1_motor_plane.3mf, 1_wheel_connector.stl, 1_wheel_connector_x4.3mf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]
2025-02-19 upgrading electronics and writing docs
    [Bugsy.kicad_sch]
2025-03-01 massive code improvements
    [Bugsy.kicad_sch]
2025-03-10 adding new parts
    [e2_pca9685.cfg]
2025-03-10 start of second build
    [1_2_mb_core_monobodies.3mf, 1_2_mb_core_monobodies.stl, 1_rear_monobody.3mf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]
2025-03-11 reworked motor plane and added more electronics
    [1_frame.stl, 1_wheel_connector.stl, 2_bearing_case.stl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]
2025-03-11 further additions to new plane and construction
    [a_bugsy.cfg]
2025-03-11 fixing typos
    [1_2_mb_core_monobodies.3mf, 1_2_mb_core_monobodies.stl, 1_wheel_connector.stl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]
2025-03-19 new structure and first hull parts
    [1_motor_plane.3mf, 1_motor_plane.stl, 2_side_connector.3mf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]
2025-03-23 improved naming standard
    [1_frame.stl, 1_wheel_connector.stl, 1_wheel_connector_x2.3mf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]
2025-03-24 adding hull parts to assembly
    [a_bugsy.cfg]
2025-04-04 removing printer files module
2025-04-29 adding new screws
    [a1_chassis.cfg, a_bugsy.cfg]
2025-04-30 massive cleanups
    [4_side_frame.stl, 4_side_frame_x2.3mf, 4a_side_frame_left.3mf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]
2025-04-30 removing slicer files
    [1_2_mb_core_monobodies.3mf, 1_motor_plane.3mf, 1_wheel_connector_x2.3mf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]
2025-05-06 3d-printing stuff
    [1_base_plating.stl, 1_motor_plane.stl, 3d_printing.xlsx]
2025-05-06 implementing more sensor data
2025-05-06 adding sensors to trader
2025-11-10 start of software and hardware seperation
    [Bugsy.kicad_pcb, Bugsy.kicad_sch]
2025-11-21 continuing on construction
    [a1.a1_chassis_side.cfg, a1_chassis.cfg, a2_motor_plane.cfg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]
2025-12-07 made further progress on shape and hull
    [4a_side_frame_left.cfg, a1_chassis.cfg, a_bugsy.cfg]
